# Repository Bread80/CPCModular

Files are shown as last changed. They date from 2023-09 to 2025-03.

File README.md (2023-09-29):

# The CPC Modular

### An Amstrad CPC compatible computer build from modules.

***This project is an unfinished work in progress. It currently has bugs and not all the features have been tested!

The current modules are designed to fit a slightly modified RC2014 Pro backplane. In the text below I shall explain the current status of the project, workarounds needed to get it running and basic build details. Due to the work in progress status of the project this document will be intentionaly terse.

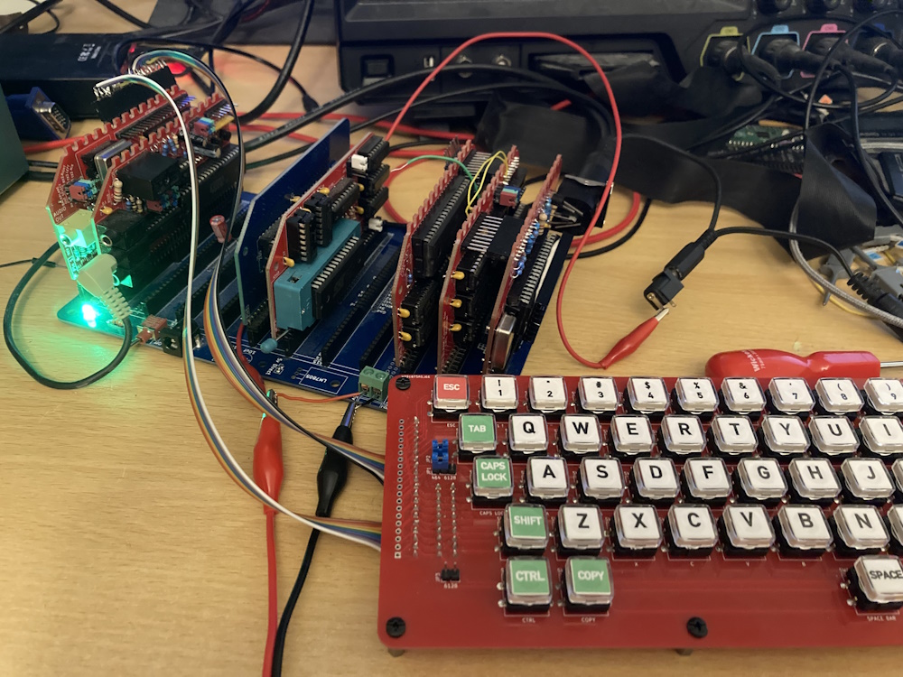
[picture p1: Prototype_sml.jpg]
Photo of the project. An RC2014 backplane in blue with modules in red.


## The modules

### General

The project uses pin header/socket to connect modules within subsystems (the video-RAM subsystem and the IO-sound sub-system). This requires longer pin header than usual.

### Backplane

This is a slightly modified RC2014 Pro backplane. The CPC Modular uses the D8 through D15 lines both within the video-RAM subsystem and the IO-Sound subsystem for local data busses. Therefore:
* You will need to sever the D8 through D15 lines between these sections. 

### CPU

This is a slightly modified RC2014 "Z80 CPU Module". Modification:
* The resistors on the board will need to be replaced with a different value. 2.2k ohm should work nicely.

### ROM

This board contains 512Kb NORFLASH. It includes circuitry to enable the flash to be burned in situ (untested). Config:
* A jumper needs to be installed bridging pin 2 of LK4 and pin 2 of LK5.
* To enable flash burning, install links LK1, LK2 and LK3. Otherwise leave open.
* My notes for writing to the Flash (taken from the schematic file) are:
> !!!
> There is no way to disable memory writes on the standard CPC system. Therefore ANY memory writes which we do to ROM while WRITE_EN is active will also write to RAM.
>
> However, since the ROM maps to any and all memory banks this adds a certain amount of flexibility. Also note that reading from ROM is disabled whilst writing is enabled. This means we can read from the RAM 'underneath' the ROM while the ROM is active.
>
> My recommended programming procedure is to write to the ROM using video RAM addresses, however the ROM could be writting using addresses in bank 1 (&4000-&7fff) if that memory range does not contain meaningful data. (If the data to be written is already in this address range then the programmer can simply read the data (RAM) and then write (ROM) at the same address. Care needs to be taking with commands sent to the ROM though, as these will still trash data underneath).
>
> 1) Read the RAM byte at the address to be programmed.
> 2) Turn on write enable for the ROM
> 3) Write the needed data to ROM.
> 4) Turn off write enable for the ROM
> 5) Write the original data back to ROM.

* The ROM (NORFLASH) can hold up to 31 ROMS plus the firmware ROM. When programming the chip, the Firmware needs to go into slot 31 (starting at address &7c000). BASIC (if installed) needs to go into slot 0 (address &00000). ROM slots are located every &4000 bytes, I.e &00000, &04000, &08000, &0C000, &10000 etc.
* If burning ROMs with the XGPro software:
  1) Use Select IC to select the IC being used (SST39FS040).
  2) Click LOAD toolbar button.
  3) Select the file to load.
  4) File Format: Binary (for .ROM files)
  5) To Region: Default
  6) Load mode: Normal
  7) From File Start Addr: 0000
  8) To Buffer Start Addr: The ROM slot start address (&7C000 for the firmware, &00000 for BASIC)
  9) Clear buffer when loading file: The option 'Clear buffer with default' will *overwrite* any previously loaded data! Use this for the first ROM loaded into XGPro (which will initialise the entire ROM). For all other ROMs select 'Disable' (which will load data only into the selected slot).
  10) Click Okay and verify you file(s) have loaded to the correct address(es) and not been overwritten.
  11) Click PROG (toolbar)
  12) Click Program.

### Video

This board houses the gate array and video output.
* On JP901 the DISPEN and HSYNC signals are swapped compared to those on the equivalent header on the RAM-Control board. This is best fixed on the RAM-Control board (see below).
* The video out circuit is that from the CPC464 but, somehow, I've used component values from the CPC6128 but minus the capacitors on the '6128. This probably doesn't make a significant difference.
* In my testing I'm using the same SCART to HDMI adapter I normally use for Amstrads but here it shows a black and white image, or no image at all. This appears to be an issue between the PSU used by the cable and the adapter. It can be fixed by feeding 5V power to the cable from the CPC Modular board.
* The board includes footprints for both 40007 and 40010 gate arrays (and a 40008 should also work). The footprints overlap to save space. You should be able to include sockets for both by separating the two rows of pins and removing the webbing between them, however, the footprints are a little too close together to do this easily.
* The holes in the footprint for the DIN socket are a little too small.

### RAM-Control

This board houses the link between the video data bus and the CPU data bus, massages the signals to make them suitable for the SRAM memory and houses the optional components required for memories greater than 64k (untested).
* The circuit driving /RAMOE is incorrect. To fix it:
  1) Cut the trace between U192 pins 1 and 13
  2) Cut the trace between U192 pin 11 and U193 pin 1
  3) Install a wire between U192 pin 1 and U195 pin 9
  4) Install a wire between U195 pin 8 and U193 pin 1
* As noted for the video board, the DISPEN and HSYNC pins are swapped on the connectors between the boards. To fix this:
  1) Cut the trace between J1 pin 2 and J2 pin 2
  2) Cut the trace between J1 pin 3 and J2 pin 3
  3) Install a wire between J1 pin 2 and J2 pin 3
  4) Install a wire between J1 pin 3 and J2 pin 2
* To use <= 64k RAM install links LK5, LK6 and LK7. If so DO NOT insert IC118 and U194
* To use > 64k RAM leave LK5, LK6, LK7 open and install IC118 and U194. IC118 is a standard Amstrad HAL/PAL.

The correct circuit to drive /RAMOE is:
```
XCPU_AD-----|
            |--
/XCPU_AD--     AND---/ROMOE
          OR---
/RAMRD----
```
In text form:
`/ROMOE := XCPU_AD AND (/XCPU_AD OR /RAMRD)`

XCPU_AD can be sourced from U195 pin 8.

### RAM

This board houses the 6845 CRTC, address multiplexers and 512Kb SRAM. There are no issues here, and no config is necessary.
* Headers can be installed for CURSOR and LPEN if required. They probably aren't.

### IO

This board houses the 8255 PIO and tape interface. Solder links and jumpers are installed to make the I/O address configurable:
* The board was designed such that the IO board could be mounted 'above/in front of' it but the relay is too tall to allow that. Thus: I'd recommend you mount J902 on the rear of the board (this is the connector to the Sound board).
* On the rear of the board find the solder links just above the address pins. On each link you need to solder the 'high' address pad (labelled A7(sic) to A15) to the central pad. The 'low' address pads (A0..A7) must NOT connected to the centre pads.
* On the front of the board find the links located between  U1 and D302. You need to jumper the 'low' link (to the centre pin) for the link labelled A3, and the high link (to the centre pin) for the others (A2, A4, A5, A6, A7).
* Find the links located between C315 and J901. The configure which signals are directed to the jack sockets and which are directed to the backplane. The recommended setup is:
  1) Install links between the INT(ernal) and middle pins for TO, TI and /MO (Tape Out, Tape In and Motor).
  2) Leave the /EXP link open.
* J901 allows access to various 8255 input signals. By default all these lines have pull-ups and can be ignored.
  1) RG0, RG1, RG2 are the region setting.
  2) VHz is the 50Hz/60Hz setting for video output.
  3) /EXP is the /EXP signal.
  4) PBSY is Printer Busy signal. The CPC Modular does not include a parallel port. This signal can be used for expansion if desired.
* J1, J2 and J3 are the tape I/O jacks. J3 (Motor) should be a 2.5mm jack socket but the footprint is for a 3.5mm socket.

### Sound

This board houses the AY-3-8910 sound generator and associated outputs, plus the keyboard and joystick connectors.
* As noted for the IO board: You should mount the inter-board connector (J902) on the top of this board, not the rear as shown in the silkscreen.
* The board has the ability to use an on-board oscillator for the AY's clock input. In the CPC Modular: Omit X1 and install a jumper at the CLK2 end of JP3 (which configures the board to use the clock signal from the gate array send through the backplane).
* The jumpers above J103 (audio out jack) allow various audio signals to be sent to a variety of backplane pins. In most cases these can be left open. Note that some of the settings may conflict with tape signals routed via the backplane on the IO board.
* If an audio jack is installed the LEFT and RIGHT signals will NOT be sent to the backplane (if configured to do so - see previous item). However the audio MIX will still be sent (if configured so).
* CP2 is the keyboard connector. This uses the same pinout as the original Amstrad CPC464 (PCB keyboard).
* J102 is the joystick connector. The connector here is mounted a little too 'inboard' and could short a PCB in the next socket.

## Links

HAL/PAL:
* Code for original: https://www.cpcwiki.eu/index.php/PAL16L8
* WiP replacement: https://github.com/Bread80/GreenHAL
* WiP replacement: https://www.cpcwiki.eu/forum/index.php?msg=231084

Gate Array:
* WiP FPGA based replacement: https://github.com/codedchip/AMSGateArray

ROM Images:
https://www.cpcwiki.eu/index.php/ROM_List

## Licence, Copyright and Contact Details

* Licence: CERN-OHL-P
* Copyright © Mike Sutton, 2023
* Website: https://bread80.com
* Social media (Mastodon): https://mstdn.social/@bread80

## Notes

There's nothing useful beyond here. But if you've made it this far you'll probably keep going anyway.

Signal lines
------------

Signals through RC2014 backplane
====

Common (whole board)
----
TX/RX=Sound (Left, right) **Jumpered (optional)
USR1=ROMDIS
USR2=/ROMEN
USR3=VSYNC (Video to IO)
USR4=<unusable>

/WAIT=READY (it already is!)
CLOCK2=/CPU_ADDR (RAM board; 1MHz clock for sound)
RX2=Tape in **Jumpered (optional)
TX2=Tape out **Jumpered (optional)
USR5=RAMDIS ***MOVED***
USR6=/RAMRD ***MOVED***
USR7=Motor **Jumpered (optional)

Video section
----
D8-D15=Video bus

IO Section
----
D8-D15=IO bus
???Control signals???

Signals through inter-board connectors
====

Video board to RAM Control board
----
Position=Top row of holes @ 45.72mm above centre of basic RC2014 header pins,
 Leftmost pins = mid-point between A9 and A8 
 Pin 1 to the right
1 GND
2 HSYNC (in)
3 DISPEN (in)
4 GND
5 /RAS (out)
6 /CAS (out)
7 /MWE (out)
8 /CCLK (out)
9 /244EN (out)
10 GND

RAM Control board to RAM board
----
Position=Top row of holes @ 43.18mm above centre of extended header pins, 
 Leftmost pins = mid-point between D2 and D3 pins
 Pin 1 to the left, all grounds on topmost row.
1=GND
2=HSYNC (in)
3=DISPEN (in)
4=/CCLK (out)
5=/XCPU_ADDR (out)
6=/RAMCS (out)
7=GND
8=/RAMOE (out)
9=GND
10=/RAMWE (out)
11=RAMA14 (out)
12=RAMA15 (out)
13=RAMA16 (out)
14=RAMA17 (out)
15=GND
16=RAMA18 (out)

IO board to Sound board
----
1=GND
2=BC1
3=BDIR
4=PC0
5=PC1
6=PC2
7=PC3
8=GND

Amstrad/MX4 pinout

Expansion  RAM Ctrl	RAM	Video	IO	AY	DDI
---
GND			
  SOUND							Y
A15			Y		Y	Y
  A14		Y		Y	Y
A13					Y
  A12				Y
A11					Y			Y
  A10				Y					Y
A9					Y			Y
  A8				Y			Y		Y
A7					Y					Y
  A6				Y
A5					Y
  A4				Y
A3					Y
  A2				Y
A1					Y			
  A0				Y					Y

D7			Y		Y			Y
  D6		Y		Y			Y
D5			Y		Y			Y
  D4		Y		Y			Y
D3			Y		Y			Y
  D2		Y		Y			Y
D1			Y		Y			Y
  D0		Y		Y			Y
					(CRTC)
VCC
  MREQ					Y
M1						Y		Y
  RFSH
IORQ				Y	Y		Y		Y
  RD				Y	Y		Y		Y
WR			Y		Y			Y		Y
  HALT
INT						Y
  NMI
BUSRQ
  BUSAK
READY		Y			Y
  BRST
RSET		Y?			Y?		Y?	Y?	Y?
  ROMEN					Y
ROMDIS		Y
  RAMRD		Y			Y
RAMDIS		
  CURSOR			Y
LPEN				Y
  EXP							Y		Y
GND
  CLK4					Y				Y

Extra (Video-RAM):
RD7..RD0	Y		Y	Y
RAS			Y			Y
CAS			Y			Y
MWE			Y			Y
244EN		Y			Y
XCPU_AD(?)	Y		Y
RAMCS		Y		Y
RAMOE		Y		Y
RAMWE		Y		Y	
RAMA18..RAMA14  Y	Y
HSYNC				Y	Y
DISPEN				Y	Y
CCLK				Y	Y
(24 lines)

Extra (Video-RAM and IO-Sound):
CPU_ADDR(1MHz) Y		Y		Y
VSYNC				Y	Y		Y
(2 lines)

Extra (IO-Sound):
PA7..PA0						Y	Y
MOTOR							Y
CASRD							Y
CASWR							Y
PRINTBUSY						(Y)
BC1								Y	Y
BDIR							Y	Y
PC3..PC0						Y	Y
LEFT								Y
RIGHT								Y
(20 lines)

Disc:
Approx 14 lines required internally

Video/RAM: 50 + 24 + 2 = 76 lines! total. Less un-needed: 69 total (70 plus one spare!)
IO/Sound: 50 + 20 + 2 = 72 lines total. Less un-needed: 50 total (inc a couple of spares)
Disc: 50 + 14 = 64 lines total

Notes:
76 pin edge connector: board width = 99.06mm

Boards:
MX4 section:
CPU
ROM
Spare(s)
RC2014
Edge connector

Video section (gate array):
Video
RAM
RAM Control

Video section (RP2040):
Video
Signals
RAM
Transceiver

Disc Section:
Controller
Connectors/Buffers

IO Sound section:
PPI
AY
Tape
Audio amp/mixer

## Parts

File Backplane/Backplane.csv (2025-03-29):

Source: | C:\Dropbox\InfoLaptop\Bread80\CPC\CPCModular\Backplane\Backplane.sch
Date: | 06/03/2024 22:52
Tool: | Eeschema (5.1.12)-1
Generator: | C:\Program Files\KiCad\bin\scripting\plugins/bom_csv_grouped_by_value_with_fp.py
Component Count: | 90
Ref | Qnty | Value | Cmp name | Footprint | Description | Vendor
C1, C3, | 2 | 220uF 100V | CP | Capacitor_THT:CP_Radial_D7.5mm_P2.50mm | Polarized capacitor
C2, | 1 | 470uF 6.3V | CP | Capacitor_THT:CP_Radial_D7.5mm_P2.50mm | Polarized capacitor
C4, | 1 | 10V 47uF | CP | Capacitor_THT:CP_Radial_D7.5mm_P2.50mm | Polarized capacitor
D1, D2, | 2 | SA5.0CA-E3/54 | D_TVS_ALT | Diode_THT:D_DO-15_P12.70mm_Horizontal | Bidirectional transient-voltage-suppression diode, filled shape
D3, | 1 | POWER | LED | LED_THT:LED_D3.0mm | Light emitting diode
D4, D5, D6, D7, D8, D9, D10, D11, D12, D13, D14, D15, D16, D17, D18, D19, D20, D21, D22, D23, D24, D25, D26, D27, D28, D29, D30, D31, D32, D33, D34, D35, D36, D37, D38, D39, D40, D41, D42, D43, D44, D45, D46, D47, D48, D49, D50, D51, | 48 | PESD5V0V1BA | D_TVS_ALT | Diode_SMD:D_SOD-323_HandSoldering | Bidirectional transient-voltage-suppression diode, filled shape
D52, | 1 | 1N4148 | 1N4148 | Diode_THT:D_DO-35_SOD27_P7.62mm_Horizontal | 100V 0.15A standard switching diode, DO-35
D53, | 1 | SA12CA | D_TVS_ALT | Diode_THT:D_DO-15_P12.70mm_Horizontal | Bidirectional transient-voltage-suppression diode, filled shape
F1, | 1 | MF-R600-2 | Fuse | Fuse:Fuse_Bourns_MF-RG600 | Fuse
H1, H2, H3, H4, H5, H6, | 6 | MountingHole_Pad | MountingHole_Pad | MountingHole:MountingHole_3.2mm_M3 | Mounting Hole with connection
J1, J2, J3, J4, | 4 | Conn_02x25_Odd_Even | Conn_02x25_Odd_Even | Connector_PinSocket_2.54mm:PinSocket_2x25_P2.54mm_Vertical | Generic connector, double row, 02x25, odd/even pin numbering scheme (row 1 odd numbers, row 2 even numbers), script generated (kicad-library-utils/schlib/autogen/connector/)
J5, J6, J7, J8, | 4 | Conn_02x36_Top_Bottom | Conn_02x36_Top_Bottom | CPCModular:Edge_Socket_2x36_2.54PS | Generic connector, double row, 02x36, top/bottom pin numbering scheme (row 1: 1...pins_per_row, row2: pins_per_row+1 ... num_pins), script generated (kicad-library-utils/schlib/autogen/connector/)
J9, J10, J11, | 3 | Conn_02x25_Top_Bottom | Conn_02x25_Top_Bottom | CPCModular:Edge_Socket_2x25_2.54PS | Generic connector, double row, 02x25, top/bottom pin numbering scheme (row 1: 1...pins_per_row, row2: pins_per_row+1 ... num_pins), script generated (kicad-library-utils/schlib/autogen/connector/)
J12, | 1 | Expansion Top (Edge connector) | Conn_01x25_Male | CPCModular:Edge25_2.54PS | Generic connector, single row, 01x25, script generated (kicad-library-utils/schlib/autogen/connector/)
J13, | 1 | Expansion Bottom (Edge connector) | Conn_01x25_Male | CPCModular:Edge25_2.54PS | Generic connector, single row, 01x25, script generated (kicad-library-utils/schlib/autogen/connector/)
J14, | 1 | USB_B | USB_B | Connector_USB:USB_B_OST_USB-B1HSxx_Horizontal | USB Type B connector
J15, | 1 | TE 171826-4 | Conn_01x04_Female | Connector_JST:JST_EH_S4B-EH_1x04_P2.50mm_Horizontal | Generic connector, single row, 01x04, script generated (kicad-library-utils/schlib/autogen/connector/)
J16, | 1 | Barrel_Jack_MountingPin | Barrel_Jack_MountingPin | Connector_BarrelJack:BarrelJack_Horizontal | DC Barrel Jack with a mounting pin
J17, | 1 | SCART POWER | Conn_01x02_Male | Connector_PinHeader_2.54mm:PinHeader_1x02_P2.54mm_Horizontal | Generic connector, single row, 01x02, script generated (kicad-library-utils/schlib/autogen/connector/)
R1, | 1 | 470 | R | Resistor_THT:R_Axial_DIN0207_L6.3mm_D2.5mm_P7.62mm_Horizontal | Resistor
R2, | 1 | 22k | R | Resistor_THT:R_Axial_DIN0207_L6.3mm_D2.5mm_P7.62mm_Horizontal | Resistor
R3, | 1 | 2k2 | R | Resistor_THT:R_Axial_DIN0207_L6.3mm_D2.5mm_P7.62mm_Horizontal | Resistor
SW1, | 1 | SSP1S1M6xEA | SW_SPDT | CPCModular:E-Switch_SSP1_M6_A | Switch, single pole double throw
SW2, | 1 | PTS645VH58-2 LFS | SW_Push | Button_Switch_THT:SW_Tactile_SPST_Angled_PTS645Vx58-2LFS | Push button switch, generic, two pins
TH1, | 1 | B57238S0709M000 | Thermistor_NTC | Varistor:RV_Disc_D15.5mm_W5.9mm_P7.5mm | Temperature dependent resistor, negative temperature coefficient
U1, | 1 | RS6-0505S | RS6-0505S | CPCModular:Recom_RS6_Series_SIP8 | Recom RS6-0505S DC/DC converter. 4.5-9Vin, 5Vout, 6W, SIP8
U2, | 1 | 74LS132 | 74LS132 | Package_DIP:DIP-14_W7.62mm_Socket | Quad 2-input NAND Schmitt trigger
U3, | 1 | TMU 3-0512 | CRE1S2412SC | Converter_DCDC:Converter_DCDC_muRata_CRE1xxxxxxSC_THT | 24V to 12V 83mA DC-DC Converter with 1kV isolation, SIP-4

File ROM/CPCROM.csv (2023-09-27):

Source: | C:\Dropbox\InfoLaptop\Bread80\CPC\CPCModular\ROM\CPCROM.sch
Date: | 01/02/2022 15:57
Tool: | Eeschema (5.1.7)-1
Generator: | C:\Program Files\KiCad\bin\scripting\plugins/bom_csv_grouped_by_value_with_fp.py
Component Count: | 26
Ref | Qnty | Value | Cmp name | Footprint | Description | Vendor
IC103, | 1 | SST39SF040 | SST39SF040 | Package_DIP:DIP-32_W15.24mm_Socket | Silicon Storage Technology (SSF) 512k x 8 Flash ROM
 |  | ZIF Socket

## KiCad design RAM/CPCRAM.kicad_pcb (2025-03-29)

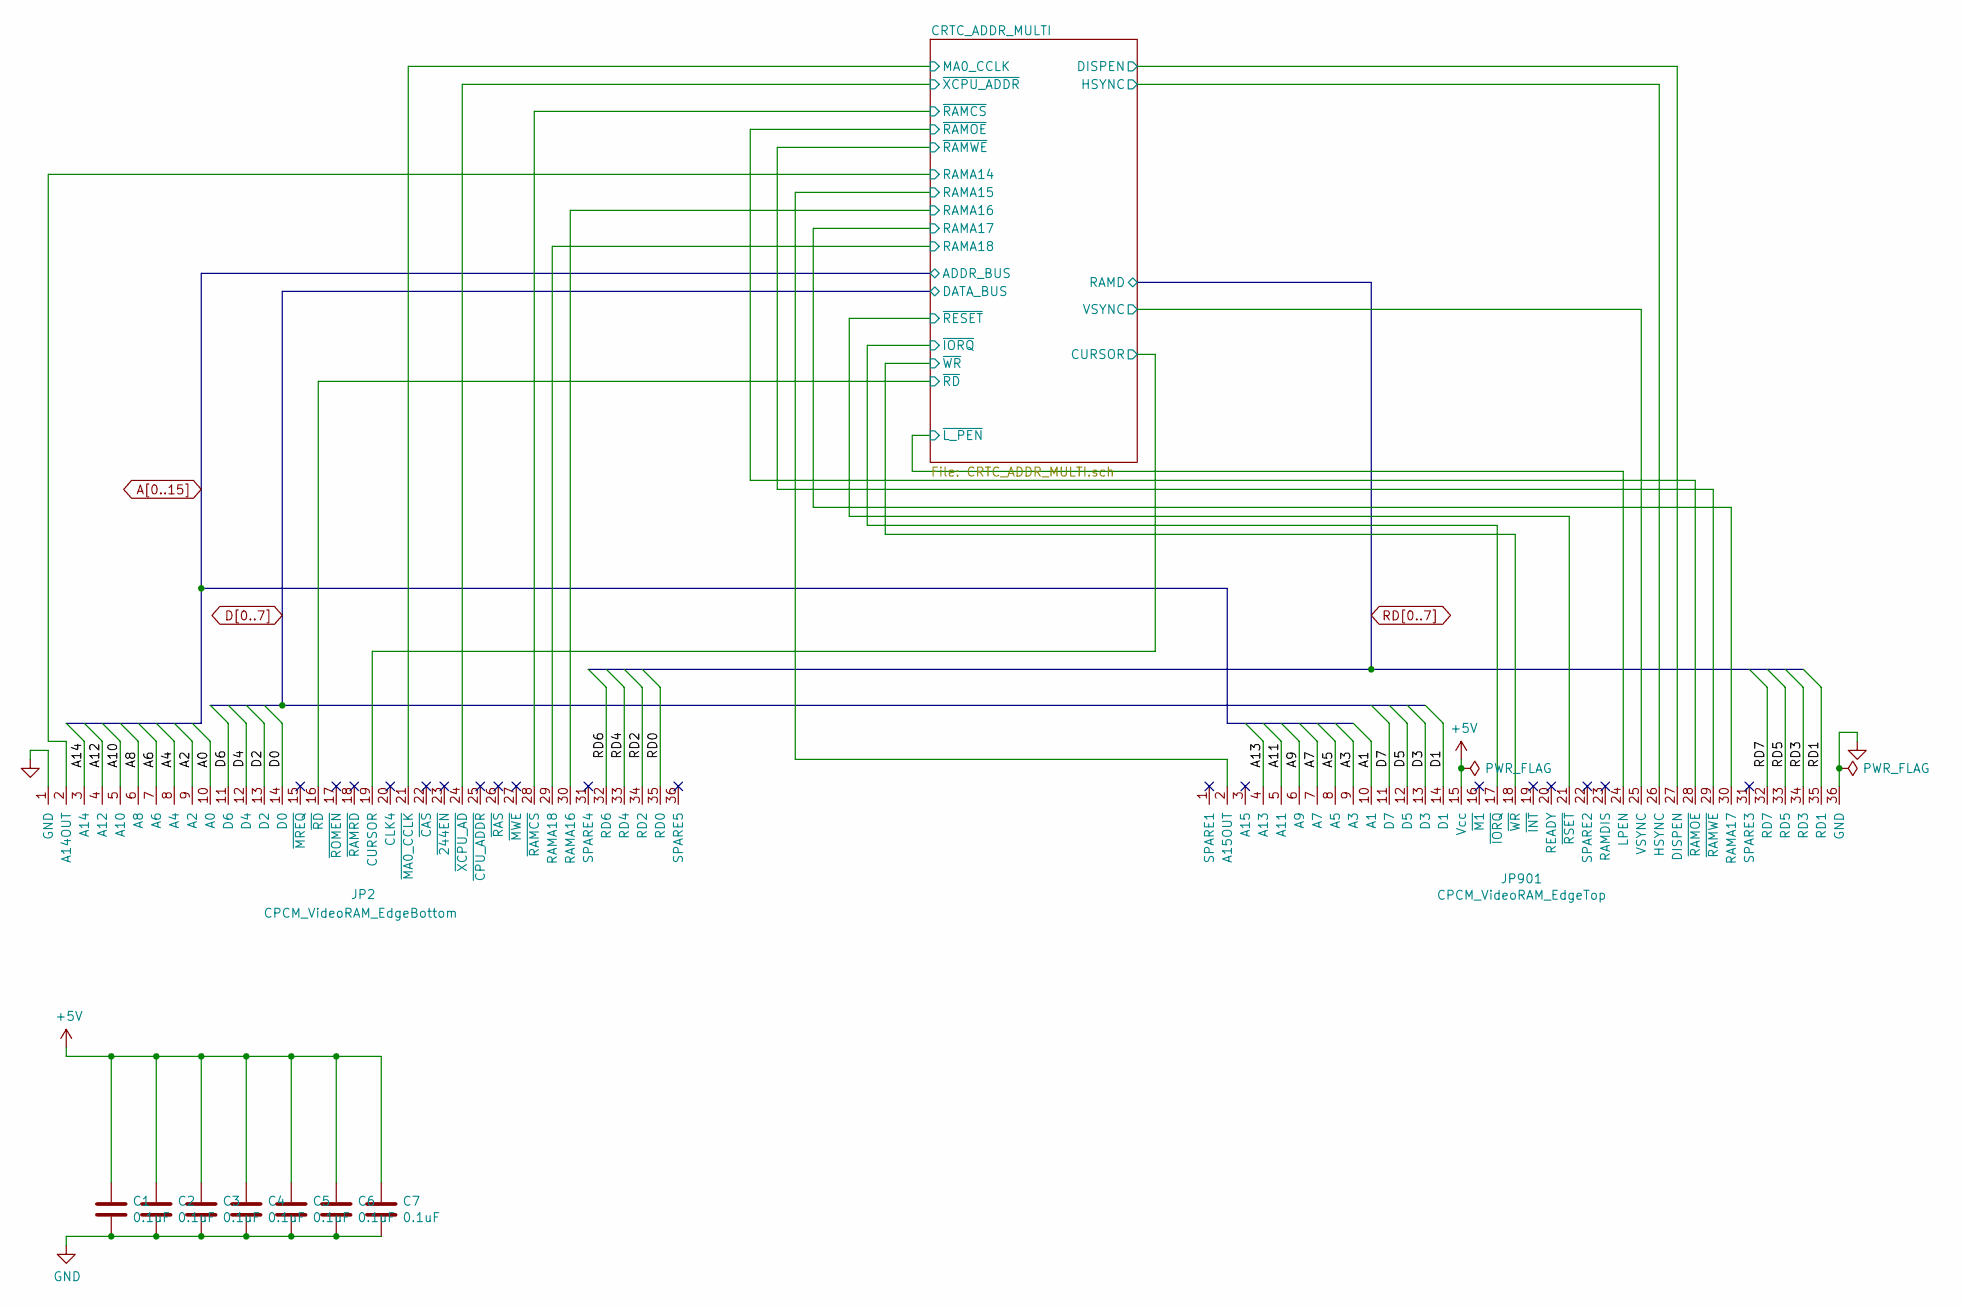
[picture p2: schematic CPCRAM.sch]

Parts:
C1, C2, C3, C4, C5, C6, C7: 0.1uF; C_Disc_D3.0mm_W2.0mm_P2.50mm
JP2: CPCM_VideoRAM_EdgeBottom; Edge36_2.54PS
JP901: CPCM_VideoRAM_EdgeTop; Edge36_2.54PS

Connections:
+5V: C1.1, C2.1, C3.1, C4.1, C5.1, C6.1, C7.1, JP901.15 (Vcc); also elsewhere on the board
/CRTC_ADDR_MULTI/A14OUT: JP2.2 (A14OUT); also elsewhere on the board
/CRTC_ADDR_MULTI/A15OUT: JP901.2 (A15OUT); also elsewhere on the board
/CRTC_ADDR_MULTI/CURSOR: JP2.19 (CURSOR); also elsewhere on the board
/CRTC_ADDR_MULTI/DISPEN: JP901.27 (DISPEN); also elsewhere on the board
/CRTC_ADDR_MULTI/HSYNC: JP901.26 (HSYNC); also elsewhere on the board
/CRTC_ADDR_MULTI/MA0_CCLK: JP2.21 (~MA0_CCLK); also elsewhere on the board
/CRTC_ADDR_MULTI/VSYNC: JP901.25 (VSYNC); also elsewhere on the board
/CRTC_ADDR_MULTI/~IORQ: JP901.17 (~IORQ); also elsewhere on the board
/CRTC_ADDR_MULTI/~L_PEN: JP901.24 (LPEN); also elsewhere on the board
/CRTC_ADDR_MULTI/~RAMCS: JP2.28 (~RAMCS); also elsewhere on the board
/CRTC_ADDR_MULTI/~RAMOE: JP901.28 (~RAMOE); also elsewhere on the board
/CRTC_ADDR_MULTI/~RAMWE: JP901.29 (~RAMWE); also elsewhere on the board
/CRTC_ADDR_MULTI/~RD: JP2.16 (~RD); also elsewhere on the board
/CRTC_ADDR_MULTI/~RESET: JP901.21 (~RSET); also elsewhere on the board
/CRTC_ADDR_MULTI/~WR: JP901.18 (~WR); also elsewhere on the board
/CRTC_ADDR_MULTI/~XCPU_ADDR: JP2.24 (~XCPU_AD); also elsewhere on the board
A0: JP2.10 (A0); also elsewhere on the board
A1: JP901.10 (A1); also elsewhere on the board
A2: JP2.9 (A2); also elsewhere on the board
A3: JP901.9 (A3); also elsewhere on the board
A4: JP2.8 (A4); also elsewhere on the board
A5: JP901.8 (A5); also elsewhere on the board
A6: JP2.7 (A6); also elsewhere on the board
A7: JP901.7 (A7); also elsewhere on the board
A8: JP2.6 (A8); also elsewhere on the board
A9: JP901.6 (A9); also elsewhere on the board
A10: JP2.5 (A10); also elsewhere on the board
A11: JP901.5 (A11); also elsewhere on the board
A12: JP2.4 (A12); also elsewhere on the board
A13: JP901.4 (A13); also elsewhere on the board
A14: JP2.3 (A14); also elsewhere on the board
D0: JP2.14 (D0); also elsewhere on the board
D1: JP901.14 (D1); also elsewhere on the board
D2: JP2.13 (D2); also elsewhere on the board
D3: JP901.13 (D3); also elsewhere on the board
D4: JP2.12 (D4); also elsewhere on the board
D5: JP901.12 (D5); also elsewhere on the board
D6: JP2.11 (D6); also elsewhere on the board
D7: JP901.11 (D7); also elsewhere on the board
GND: C1.2, C2.2, C3.2, C4.2, C5.2, C6.2, C7.2, JP2.1 (GND), JP901.36 (GND); also elsewhere on the board
RAMA16: JP2.30 (RAMA16); also elsewhere on the board
RAMA17: JP901.30 (RAMA17); also elsewhere on the board
RAMA18: JP2.29 (RAMA18); also elsewhere on the board
RD0: JP2.35 (RD0); also elsewhere on the board
RD1: JP901.35 (RD1); also elsewhere on the board
RD2: JP2.34 (RD2); also elsewhere on the board
RD3: JP901.34 (RD3); also elsewhere on the board
RD4: JP2.33 (RD4); also elsewhere on the board
RD5: JP901.33 (RD5); also elsewhere on the board
RD6: JP2.32 (RD6); also elsewhere on the board
RD7: JP901.32 (RD7); also elsewhere on the board

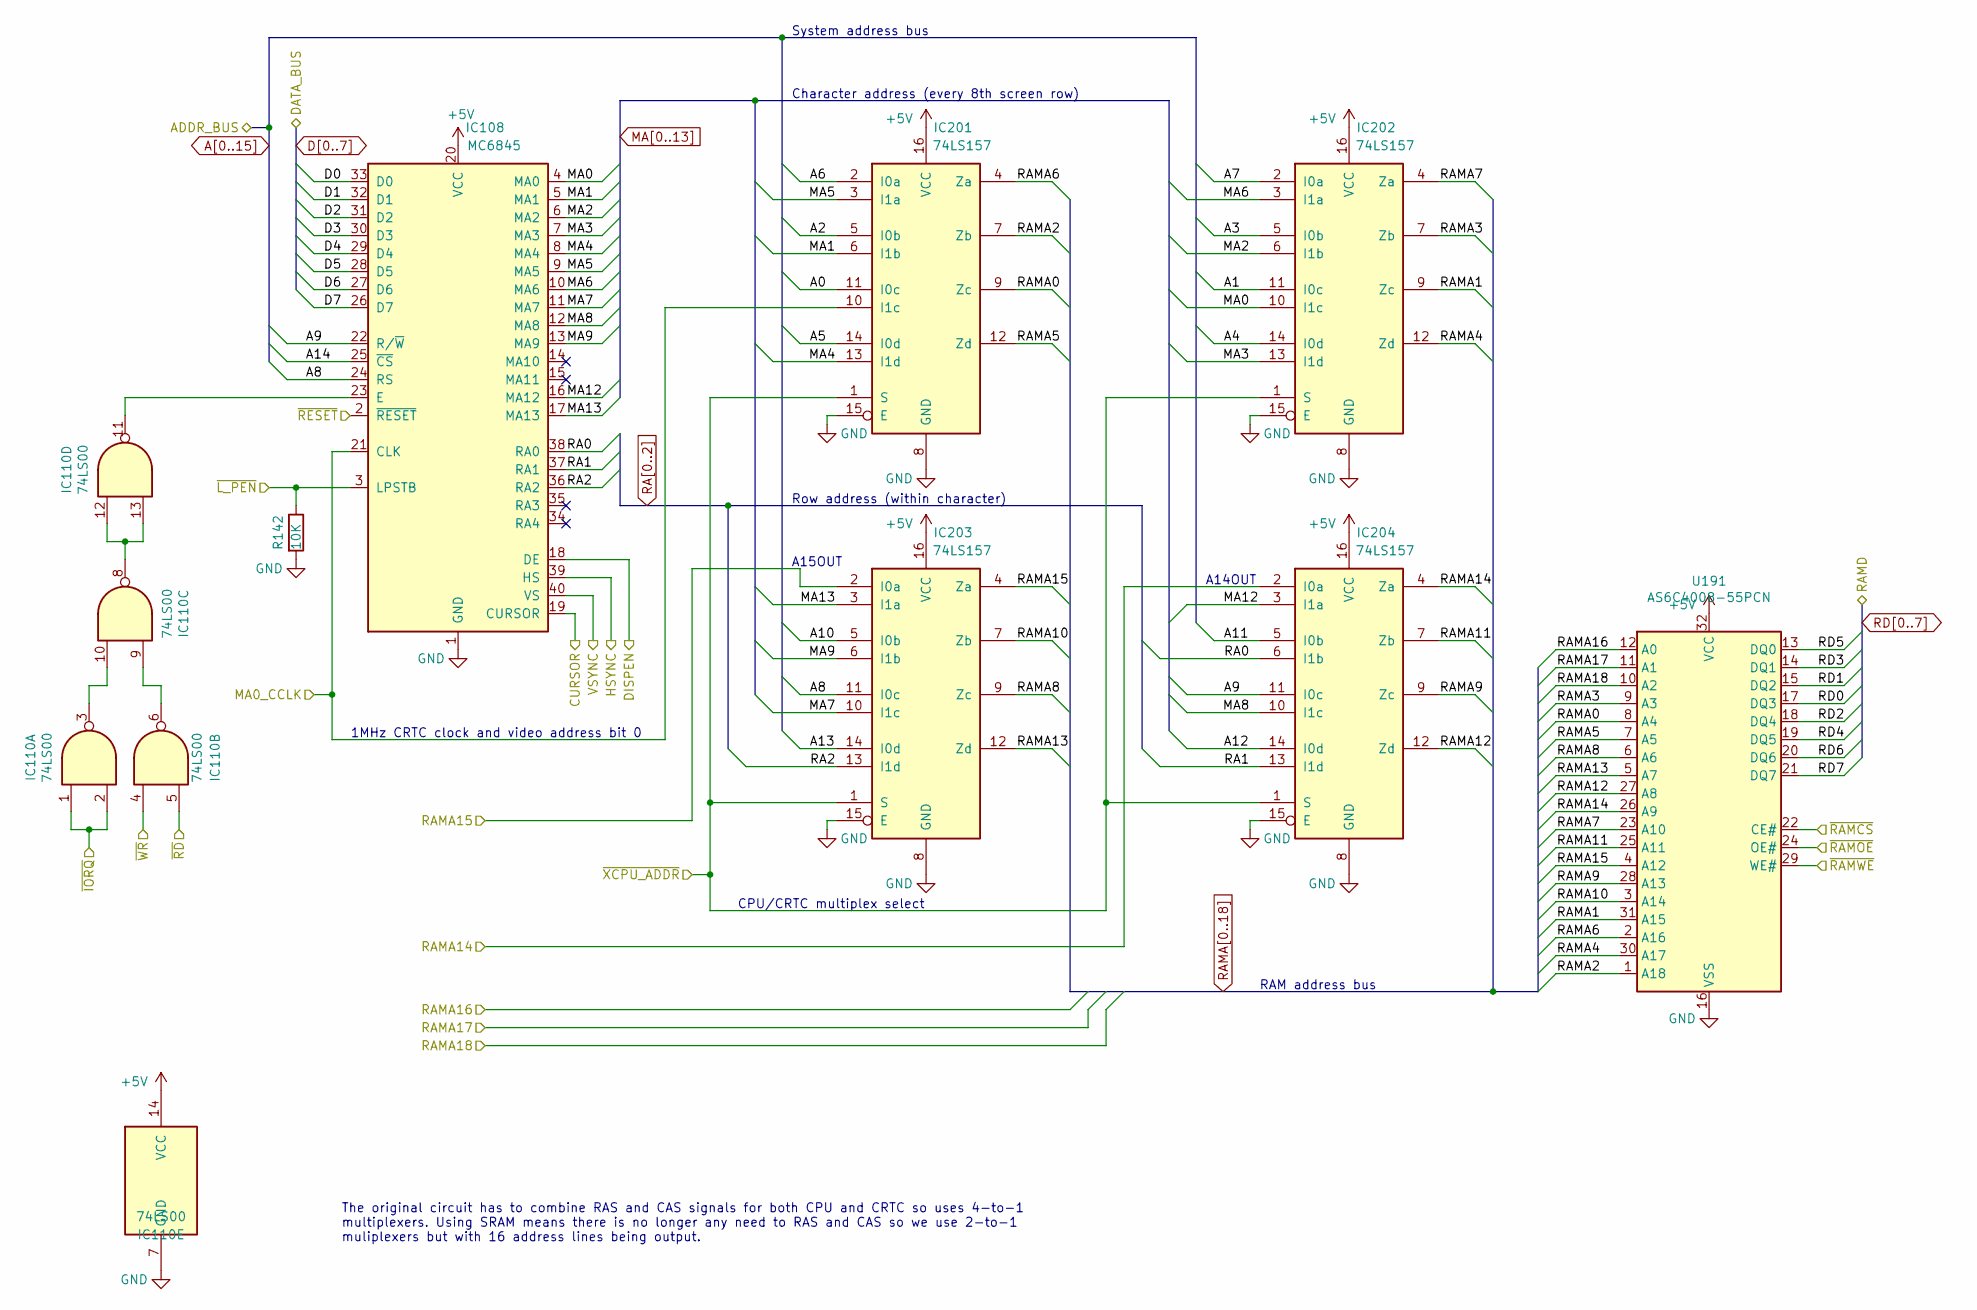
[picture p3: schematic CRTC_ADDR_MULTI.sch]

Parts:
IC108: MC6845; DIP-40_W15.24mm_Socket
IC110: 74LS00; DIP-14_W7.62mm_Socket
IC201, IC202, IC203, IC204: 74LS157; DIP-16_W7.62mm_Socket
R142: 10K; R_Axial_DIN0207_L6.3mm_D2.5mm_P7.62mm_Horizontal
U191: AS6C4008-55PCN; DIP-32_W15.24mm

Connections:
+5V: IC108.20 (VCC), IC110.14 (VCC), IC201.16 (VCC), IC202.16 (VCC), IC203.16 (VCC), IC204.16 (VCC), U191.32 (VCC); also elsewhere on the board
/CRTC_ADDR_MULTI/A14OUT: IC204.2 (I0a); also elsewhere on the board
/CRTC_ADDR_MULTI/A15OUT: IC203.2 (I0a); also elsewhere on the board
/CRTC_ADDR_MULTI/CURSOR: IC108.19 (CURSOR); also elsewhere on the board
/CRTC_ADDR_MULTI/DISPEN: IC108.18 (DE); also elsewhere on the board
/CRTC_ADDR_MULTI/HSYNC: IC108.39 (HS); also elsewhere on the board
/CRTC_ADDR_MULTI/MA0_CCLK: IC108.21 (CLK), IC201.10 (I1c); also elsewhere on the board
/CRTC_ADDR_MULTI/VSYNC: IC108.40 (VS); also elsewhere on the board
/CRTC_ADDR_MULTI/~IORQ: IC110.1, IC110.2; also elsewhere on the board
/CRTC_ADDR_MULTI/~L_PEN: IC108.3 (LPSTB), R142.1; also elsewhere on the board
/CRTC_ADDR_MULTI/~RAMCS: U191.22 (CE#); also elsewhere on the board
/CRTC_ADDR_MULTI/~RAMOE: U191.24 (OE#); also elsewhere on the board
/CRTC_ADDR_MULTI/~RAMWE: U191.29 (WE#); also elsewhere on the board
/CRTC_ADDR_MULTI/~RD: IC110.5; also elsewhere on the board
/CRTC_ADDR_MULTI/~RESET: IC108.2 (~RESET); also elsewhere on the board
/CRTC_ADDR_MULTI/~WR: IC110.4; also elsewhere on the board
/CRTC_ADDR_MULTI/~XCPU_ADDR: IC201.1 (S), IC202.1 (S), IC203.1 (S), IC204.1 (S); also elsewhere on the board
A0: IC201.11 (I0c); also elsewhere on the board
A1: IC202.11 (I0c); also elsewhere on the board
A2: IC201.5 (I0b); also elsewhere on the board
A3: IC202.5 (I0b); also elsewhere on the board
A4: IC202.14 (I0d); also elsewhere on the board
A5: IC201.14 (I0d); also elsewhere on the board
A6: IC201.2 (I0a); also elsewhere on the board
A7: IC202.2 (I0a); also elsewhere on the board
A8: IC108.24 (RS), IC203.11 (I0c); also elsewhere on the board
A9: IC108.22 (R/~W), IC204.11 (I0c); also elsewhere on the board
A10: IC203.5 (I0b); also elsewhere on the board
A11: IC204.5 (I0b); also elsewhere on the board
A12: IC204.14 (I0d); also elsewhere on the board
A13: IC203.14 (I0d); also elsewhere on the board
A14: IC108.25 (~CS); also elsewhere on the board
D0: IC108.33 (D0); also elsewhere on the board
D1: IC108.32 (D1); also elsewhere on the board
D2: IC108.31 (D2); also elsewhere on the board
D3: IC108.30 (D3); also elsewhere on the board
D4: IC108.29 (D4); also elsewhere on the board
D5: IC108.28 (D5); also elsewhere on the board
D6: IC108.27 (D6); also elsewhere on the board
D7: IC108.26 (D7); also elsewhere on the board
GND: IC108.1 (GND), IC110.7 (GND), IC201.8 (GND), IC201.15 (E), IC202.8 (GND), IC202.15 (E), IC203.8 (GND), IC203.15 (E), IC204.8 (GND), IC204.15 (E), R142.2, U191.16 (VSS); also elsewhere on the board
MA0: IC108.4 (MA0), IC202.10 (I1c)
MA1: IC108.5 (MA1), IC201.6 (I1b)
MA2: IC108.6 (MA2), IC202.6 (I1b)
MA3: IC108.7 (MA3), IC202.13 (I1d)
MA4: IC108.8 (MA4), IC201.13 (I1d)
MA5: IC108.9 (MA5), IC201.3 (I1a)
MA6: IC108.10 (MA6), IC202.3 (I1a)
MA7: IC108.11 (MA7), IC203.10 (I1c)
MA8: IC108.12 (MA8), IC204.10 (I1c)
MA9: IC108.13 (MA9), IC203.6 (I1b)
MA12: IC108.16 (MA12), IC204.3 (I1a)
MA13: IC108.17 (MA13), IC203.3 (I1a)
unnamed: IC108.23 (E), IC110.11
unnamed: IC110.6, IC110.9
unnamed: IC110.3, IC110.10
unnamed: IC110.8, IC110.12, IC110.13
RA0: IC108.38 (RA0), IC204.6 (I1b)
RA1: IC108.37 (RA1), IC204.13 (I1d)
RA2: IC108.36 (RA2), IC203.13 (I1d)
RAMA0: IC201.9 (Zc), U191.8 (A4)
RAMA1: IC202.9 (Zc), U191.31 (A15)
RAMA2: IC201.7 (Zb), U191.1 (A18)
RAMA3: IC202.7 (Zb), U191.9 (A3)
RAMA4: IC202.12 (Zd), U191.30 (A17)
RAMA5: IC201.12 (Zd), U191.7 (A5)
RAMA6: IC201.4 (Za), U191.2 (A16)
RAMA7: IC202.4 (Za), U191.23 (A10)
RAMA8: IC203.9 (Zc), U191.6 (A6)
RAMA9: IC204.9 (Zc), U191.28 (A13)
RAMA10: IC203.7 (Zb), U191.3 (A14)
RAMA11: IC204.7 (Zb), U191.25 (A11)
RAMA12: IC204.12 (Zd), U191.27 (A8)
RAMA13: IC203.12 (Zd), U191.5 (A7)
RAMA14: IC204.4 (Za), U191.26 (A9)
RAMA15: IC203.4 (Za), U191.4 (A12)
RAMA16: U191.12 (A0); also elsewhere on the board
RAMA17: U191.11 (A1); also elsewhere on the board
RAMA18: U191.10 (A2); also elsewhere on the board
RD0: U191.17 (DQ3); also elsewhere on the board
RD1: U191.15 (DQ2); also elsewhere on the board
RD2: U191.18 (DQ4); also elsewhere on the board
RD3: U191.14 (DQ1); also elsewhere on the board
RD4: U191.19 (DQ5); also elsewhere on the board
RD5: U191.13 (DQ0); also elsewhere on the board
RD6: U191.20 (DQ6); also elsewhere on the board
RD7: U191.21 (DQ7); also elsewhere on the board

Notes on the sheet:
The original circuit has to combine RAS and CAS signals for both CPU and CRTC so uses 4-to-1 multiplexers. Using SRAM means there is no longer any need to RAS and CAS so we use 2-to-1 muliplexers but with 16 address lines being output.
Row address (within character)
Character address (every 8th screen row)
CPU/CRTC multiplex select
1MHz CRTC clock and video address bit 0
System address bus
A14OUT
A15OUT
RAM address bus

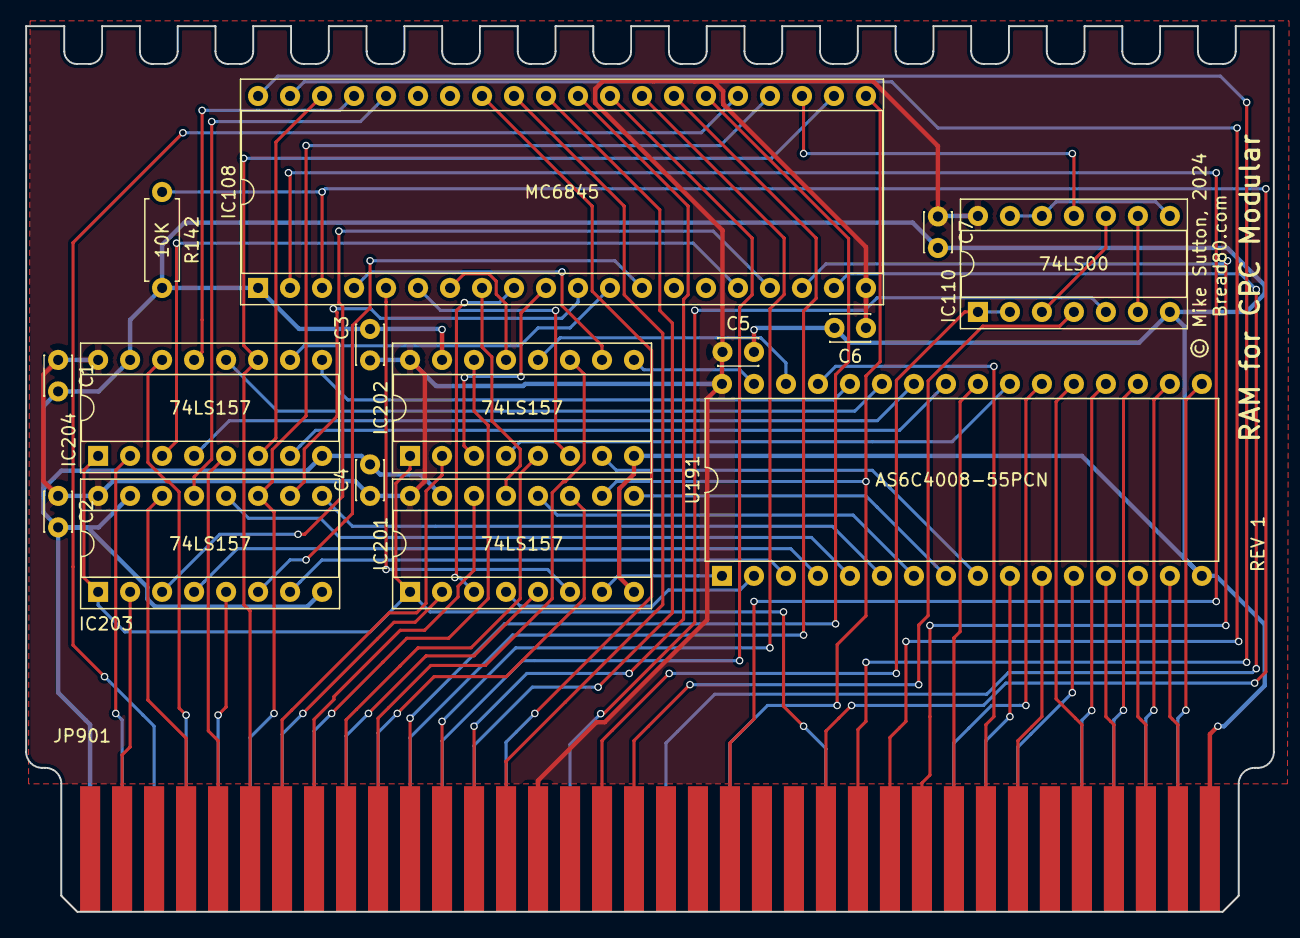
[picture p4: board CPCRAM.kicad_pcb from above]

Board: 2 copper layers, 99.1 x 70.3 mm, 17 parts (1 on the bottom side), 87 nets.

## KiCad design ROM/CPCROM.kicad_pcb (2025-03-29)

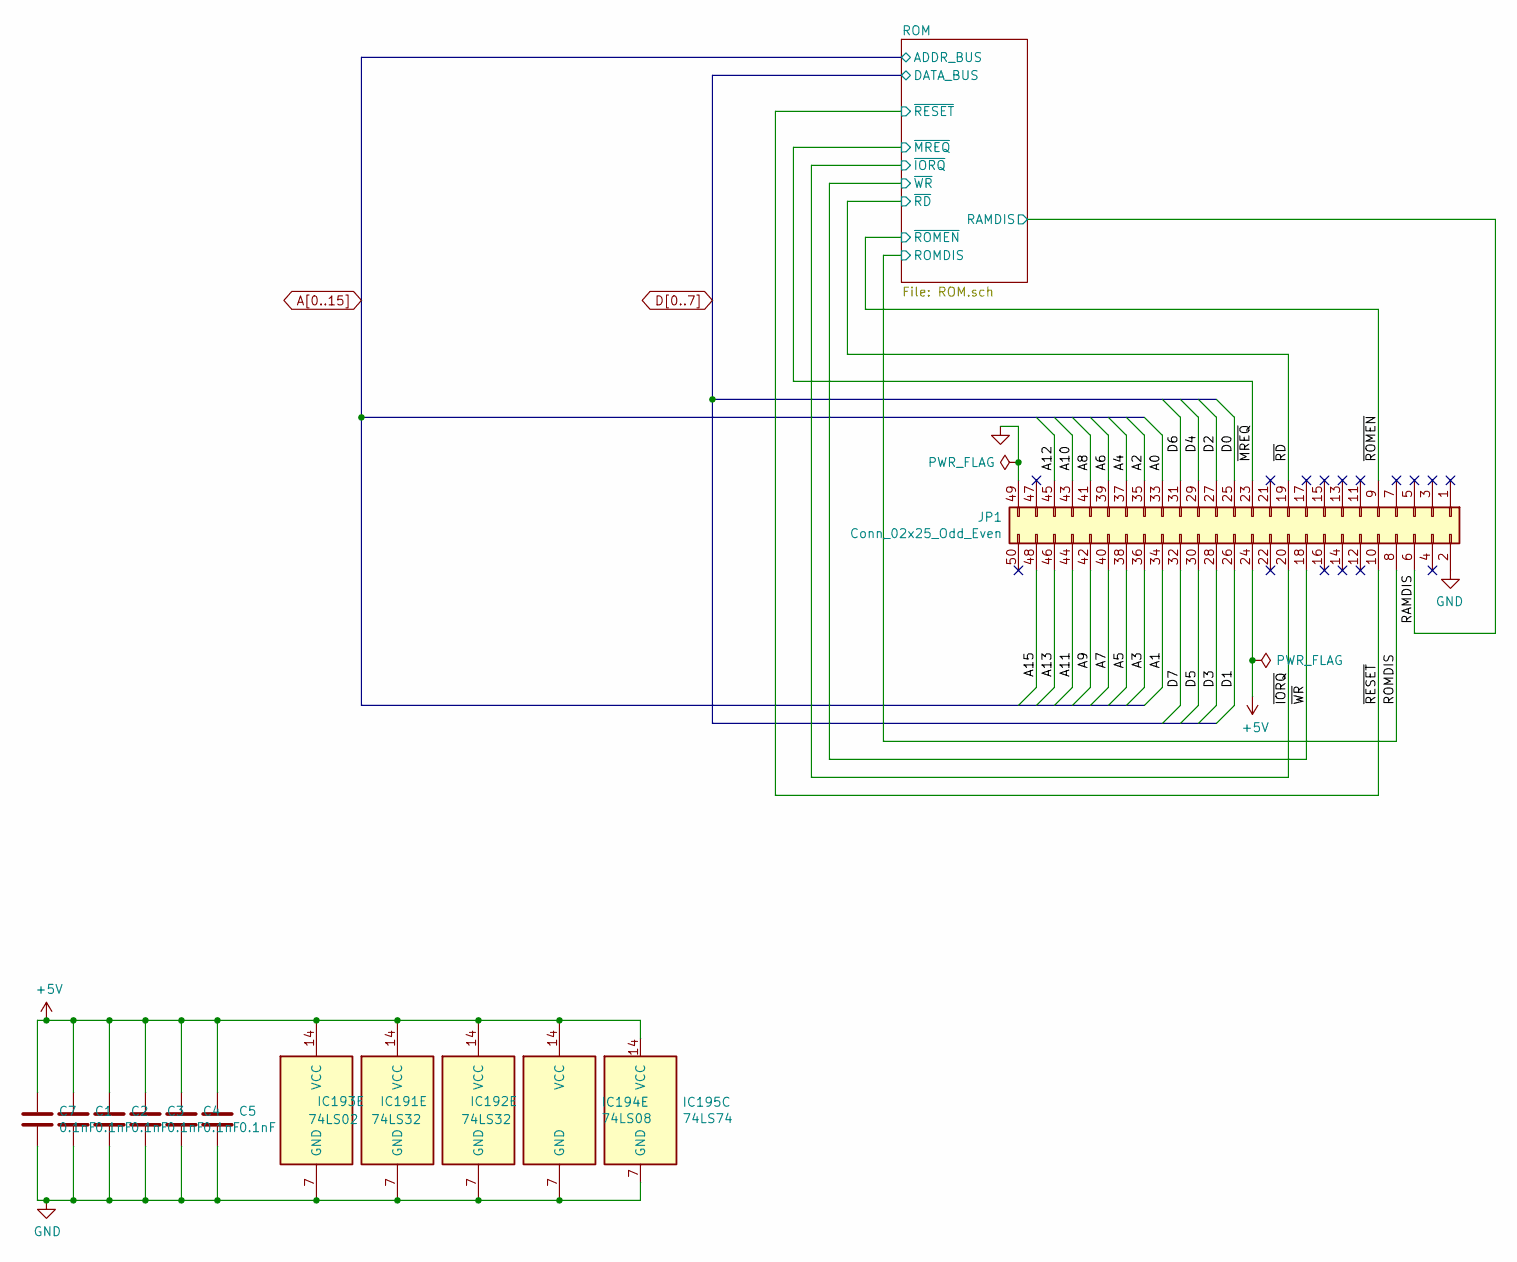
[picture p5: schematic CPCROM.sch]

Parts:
C1, C2, C3, C4, C5, C7: 0.1nF; C_Disc_D3.0mm_W2.0mm_P2.50mm
IC191, IC192: 74LS32
IC193: 74LS02
IC194: 74LS08
IC195: 74LS74
JP1: Conn_02x25_Odd_Even; IDC-Header_2x25_P2.54mm_Horizontal

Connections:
+5V: C1.1, C2.1, C3.1, C4.1, C5.1, C7.1, IC191.14 (VCC), IC192.14 (VCC), IC193.14 (VCC), IC194.14 (VCC), IC195.14 (VCC), JP1.24; also elsewhere on the board
/RAMDIS: JP1.6; also elsewhere on the board
/ROMDIS: JP1.8; also elsewhere on the board
/~IORQ: JP1.20; also elsewhere on the board
/~MREQ: JP1.23; also elsewhere on the board
/~RD: JP1.19; also elsewhere on the board
/~RESET: JP1.10; also elsewhere on the board
/~ROMEN: JP1.9; also elsewhere on the board
/~WR: JP1.18; also elsewhere on the board
A0: JP1.33; also elsewhere on the board
A1: JP1.34; also elsewhere on the board
A2: JP1.35; also elsewhere on the board
A3: JP1.36; also elsewhere on the board
A4: JP1.37; also elsewhere on the board
A5: JP1.38; also elsewhere on the board
A6: JP1.39; also elsewhere on the board
A7: JP1.40; also elsewhere on the board
A8: JP1.41; also elsewhere on the board
A9: JP1.42; also elsewhere on the board
A10: JP1.43; also elsewhere on the board
A11: JP1.44; also elsewhere on the board
A12: JP1.45; also elsewhere on the board
A13: JP1.46; also elsewhere on the board
A15: JP1.48; also elsewhere on the board
D0: JP1.25; also elsewhere on the board
D1: JP1.26; also elsewhere on the board
D2: JP1.27; also elsewhere on the board
D3: JP1.28; also elsewhere on the board
D4: JP1.29; also elsewhere on the board
D5: JP1.30; also elsewhere on the board
D6: JP1.31; also elsewhere on the board
D7: JP1.32; also elsewhere on the board
GND: C1.2, C2.2, C3.2, C4.2, C5.2, C7.2, IC191.7 (GND), IC192.7 (GND), IC193.7 (GND), IC194.7 (GND), IC195.7 (GND), JP1.2, JP1.49; also elsewhere on the board

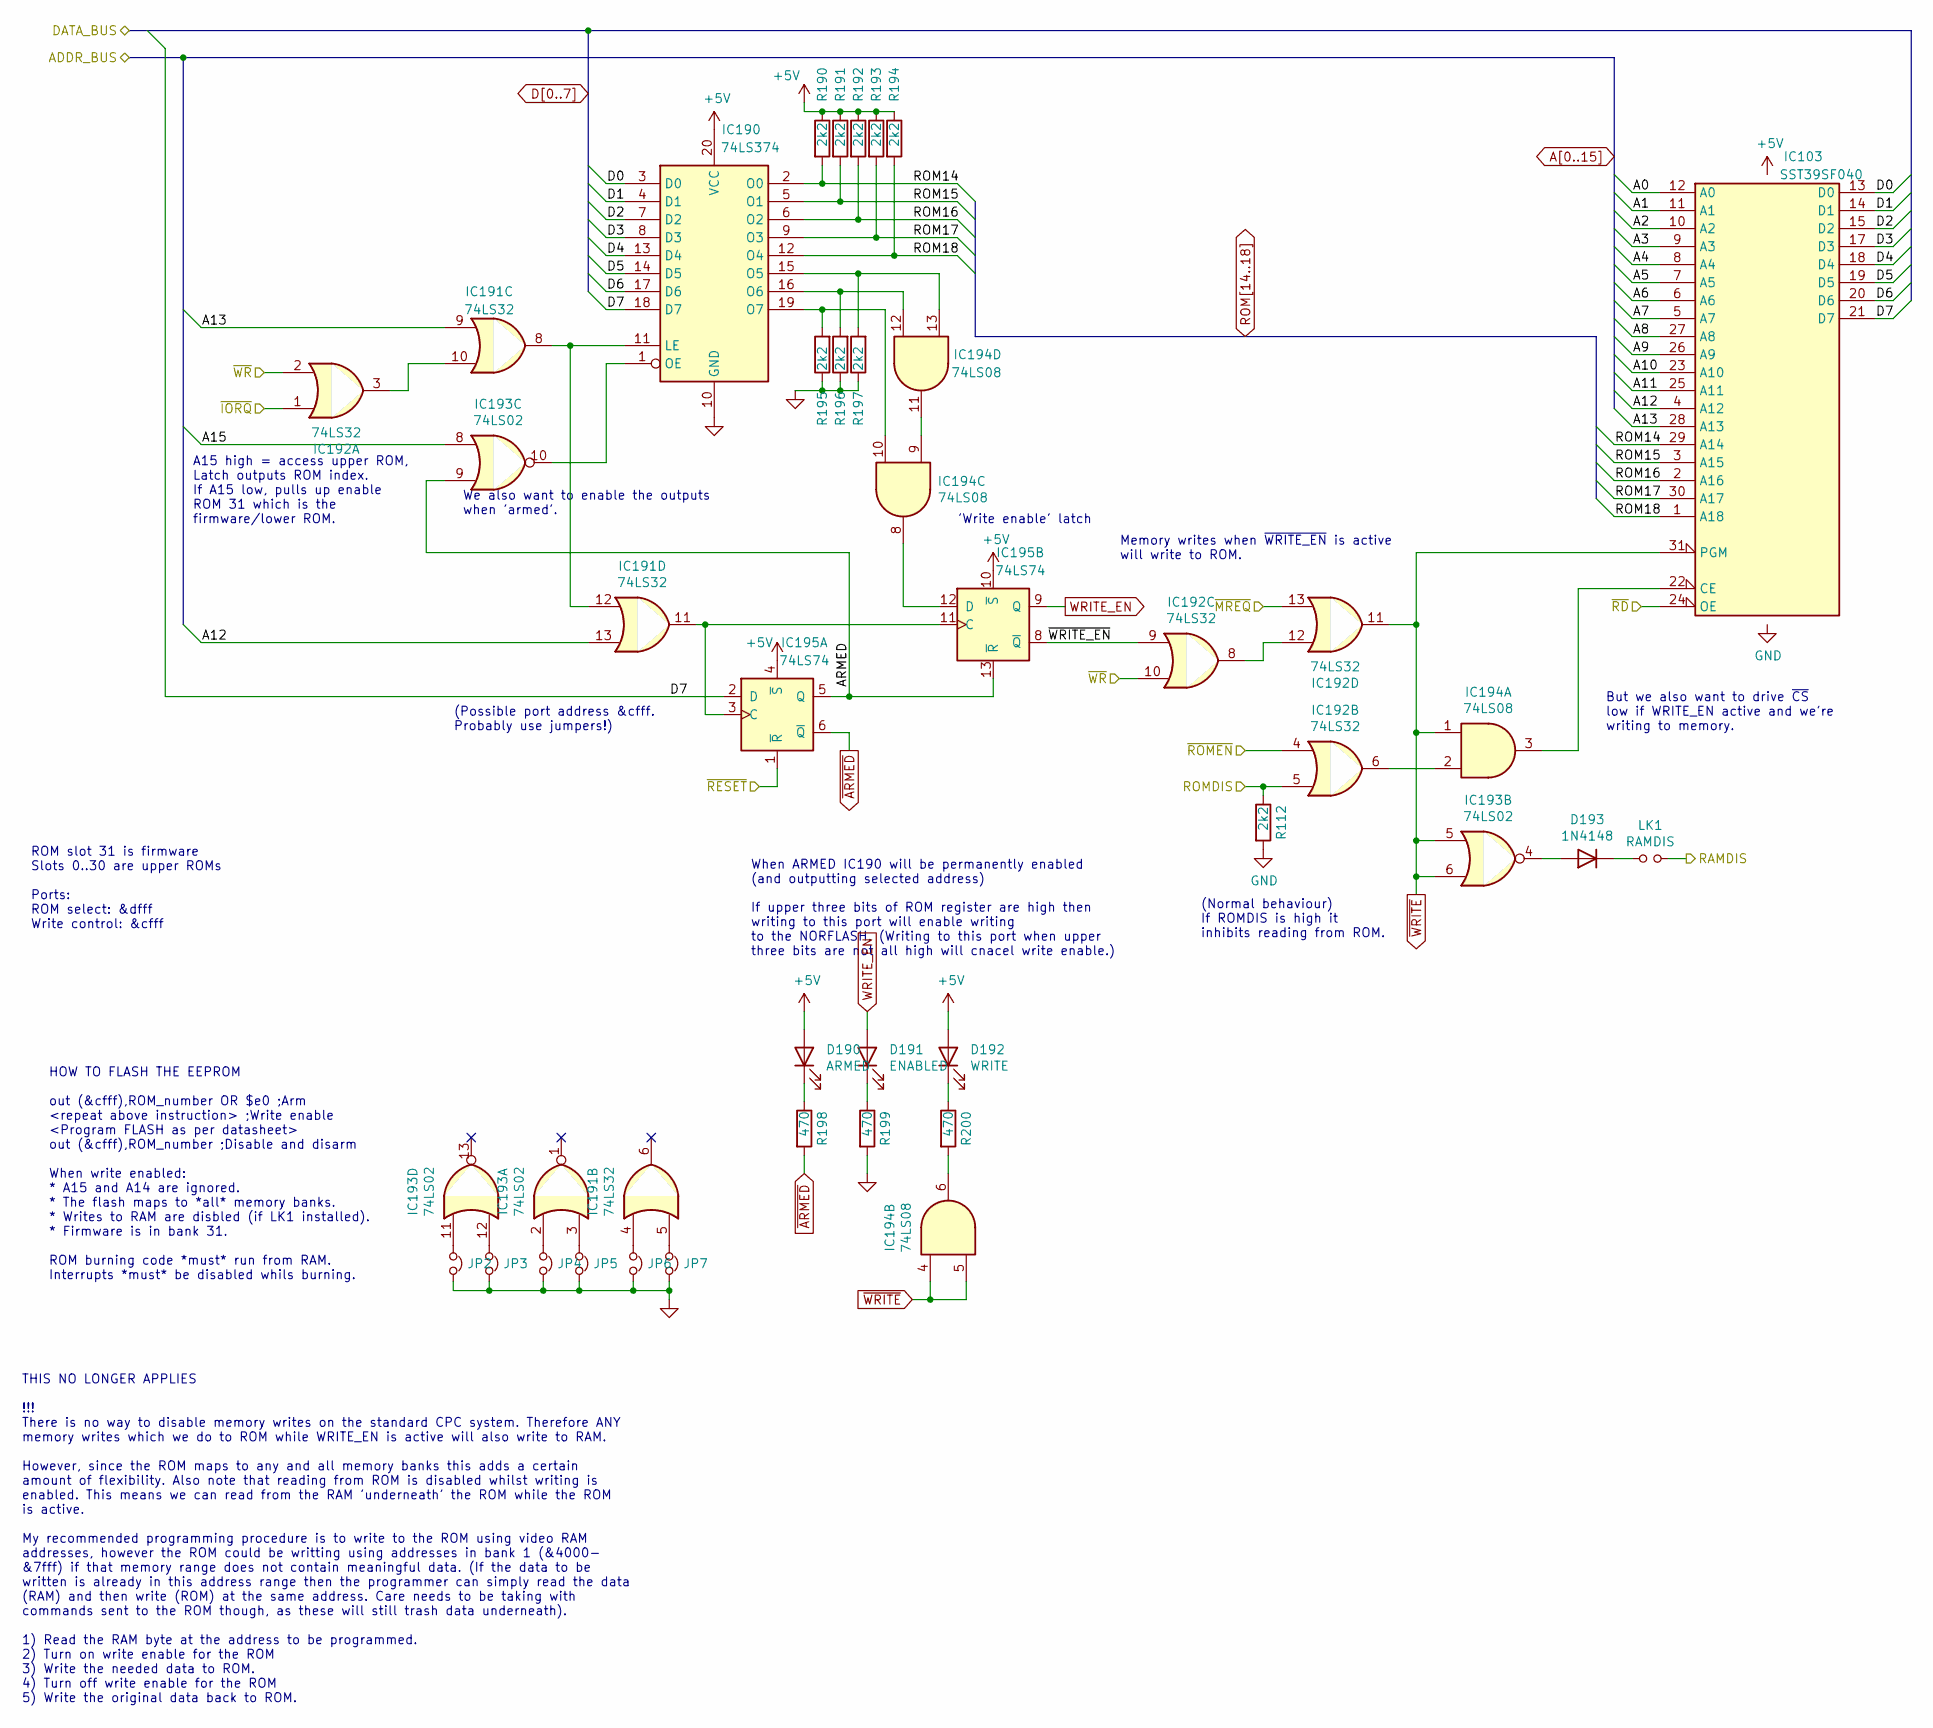
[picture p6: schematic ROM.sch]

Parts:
D190: ARMED; LED_D3.0mm
D191: ENABLED; LED_D3.0mm
D192: WRITE; LED_D3.0mm
D193: 1N4148; D_DO-35_SOD27_P7.62mm_Horizontal
IC103: SST39SF040; DIP_Socket-32_W11.9_W12.7_W15.24_W17.78_W18.5_3M_232-1285-0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
IC190: 74LS374; DIP-20_W7.62mm_Socket
IC191, IC192: 74LS32; DIP-14_W7.62mm_Socket
IC193: 74LS02; DIP-14_W7.62mm_Socket
IC194: 74LS08; DIP-14_W7.62mm_Socket
IC195: 74LS74; DIP-14_W7.62mm_Socket
JP2, JP3, JP4, JP5, JP6, JP7: Jumper_NC_Small; SolderJumper-2_P1.3mm_Bridged_RoundedPad1.0x1.5mm
LK1: RAMDIS; PinHeader_1x02_P2.54mm_Vertical
R112, R190, R191, R192, R193, R194, R195, R196, R197: 2k2; R_Axial_DIN0207_L6.3mm_D2.5mm_P7.62mm_Horizontal
R198, R199, R200: 470; R_Axial_DIN0207_L6.3mm_D2.5mm_P7.62mm_Horizontal

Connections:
+5V: D190.2 (A), D192.2 (A), IC103.32 (VCC), IC190.20 (VCC), IC195.4 (~S), IC195.10 (~S), R190.1, R191.1, R192.1, R193.1, R194.1; also elsewhere on the board
/RAMDIS: LK1.2; also elsewhere on the board
/ROM/ARMED: IC193.9, IC195.5 (Q), IC195.13 (~R)
/ROM/~WRITE_EN: IC192.9, IC195.8 (~Q)
/ROMDIS: IC192.5, R112.1; also elsewhere on the board
/~IORQ: IC192.1; also elsewhere on the board
/~MREQ: IC192.13; also elsewhere on the board
/~RD: IC103.24 (OE); also elsewhere on the board
/~RESET: IC195.1 (~R); also elsewhere on the board
/~ROMEN: IC192.4; also elsewhere on the board
/~WR: IC192.2, IC192.10; also elsewhere on the board
A0: IC103.12 (A0); also elsewhere on the board
A1: IC103.11 (A1); also elsewhere on the board
A2: IC103.10 (A2); also elsewhere on the board
A3: IC103.9 (A3); also elsewhere on the board
A4: IC103.8 (A4); also elsewhere on the board
A5: IC103.7 (A5); also elsewhere on the board
A6: IC103.6 (A6); also elsewhere on the board
A7: IC103.5 (A7); also elsewhere on the board
A8: IC103.27 (A8); also elsewhere on the board
A9: IC103.26 (A9); also elsewhere on the board
A10: IC103.23 (A10); also elsewhere on the board
A11: IC103.25 (A11); also elsewhere on the board
A12: IC103.4 (A12), IC191.13; also elsewhere on the board
A13: IC103.28 (A13), IC191.9; also elsewhere on the board
A15: IC193.8; also elsewhere on the board
D0: IC103.13 (D0), IC190.3 (D0); also elsewhere on the board
D1: IC103.14 (D1), IC190.4 (D1); also elsewhere on the board
D2: IC103.15 (D2), IC190.7 (D2); also elsewhere on the board
D3: IC103.17 (D3), IC190.8 (D3); also elsewhere on the board
D4: IC103.18 (D4), IC190.13 (D4); also elsewhere on the board
D5: IC103.19 (D5), IC190.14 (D5); also elsewhere on the board
D6: IC103.20 (D6), IC190.17 (D6); also elsewhere on the board
D7: IC103.21 (D7), IC190.18 (D7), IC195.2 (D); also elsewhere on the board
GND: IC103.16 (GND), IC190.10 (GND), JP2.2, JP3.2, JP4.2, JP5.2, JP6.2, JP7.2, R112.2, R195.1, R196.1, R197.1, R199.2; also elsewhere on the board
unnamed: D190.1 (K), R198.1
unnamed: D191.1 (K), R199.1
unnamed: D192.1 (K), R200.1
unnamed: D193.1 (K), LK1.1
unnamed: D193.2 (A), IC193.4
unnamed: IC103.22 (CE), IC194.3
unnamed: IC190.1 (OE), IC193.10
unnamed: IC190.11 (LE), IC191.8, IC191.12
unnamed: IC190.15 (O5), IC194.13, R197.2
unnamed: IC190.16 (O6), IC194.12, R196.2
unnamed: IC190.19 (O7), IC194.10, R195.2
unnamed: IC191.4, JP6.1
unnamed: IC191.5, JP7.1
unnamed: IC191.10, IC192.3
unnamed: IC191.11, IC195.3 (C), IC195.11 (C)
unnamed: IC192.6, IC194.2
unnamed: IC192.8, IC192.12
unnamed: IC193.2, JP4.1
unnamed: IC193.3, JP5.1
unnamed: IC193.11, JP2.1
unnamed: IC193.12, JP3.1
unnamed: IC194.6, R200.2
unnamed: IC194.8, IC195.12 (D)
unnamed: IC194.9, IC194.11
ROM14: IC103.29 (A14), IC190.2 (O0), R190.2
ROM15: IC103.3 (A15), IC190.5 (O1), R191.2
ROM16: IC103.2 (A16), IC190.6 (O2), R192.2
ROM17: IC103.30 (A17), IC190.9 (O3), R193.2
ROM18: IC103.1 (A18), IC190.12 (O4), R194.2
WRITE: IC103.31 (PGM), IC192.11, IC193.5, IC193.6, IC194.1, IC194.4, IC194.5
WRITE_EN: D191.2 (A), IC195.9 (Q)
~ARMED: IC195.6 (~Q), R198.2

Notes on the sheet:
A15 high = access upper ROM, Latch outputs ROM index. If A15 low, pulls up enable ROM 31 which is the firmware/lower ROM.
'Write enable' latch
(Possible port address &cfff. Probably use jumpers!)
If upper three bits of ROM register are high then writing to this port will enable writing to the NORFLASH. (Writing to this port when upper three bits are not all high will cnacel write enable.)
Memory writes when ~WRITE_EN~ is active will write to ROM.
(Normal behaviour) If ROMDIS is high it inhibits reading from ROM.
But we also want to drive ~CS~ low if WRITE_EN active and we're writing to memory.
THIS NO LONGER APPLIES !!! There is no way to disable memory writes on the standard CPC system. Therefore ANY memory writes which we do to ROM while WRITE_EN is active will also write to RAM. However, since the ROM maps to any and all memory banks this adds a certain amount of flexibility. Also not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
HOW TO FLASH THE EEPROM out (&cfff),ROM_number OR $e0 ;Arm <repeat above instruction> ;Write enable <Program FLASH as per datasheet> out (&cfff),ROM_number ;Disable and disarm When write enabled: * A15 and A14 are ignored. * The flash maps to *all* memory banks. * Writes to RAM are disbled (if LK1 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
We also want to enable the outputs when 'armed'.
When ARMED IC190 will be permanently enabled (and outputting selected address)
ROM slot 31 is firmware Slots 0..30 are upper ROMs Ports: ROM select: &dfff Write control: &cfff

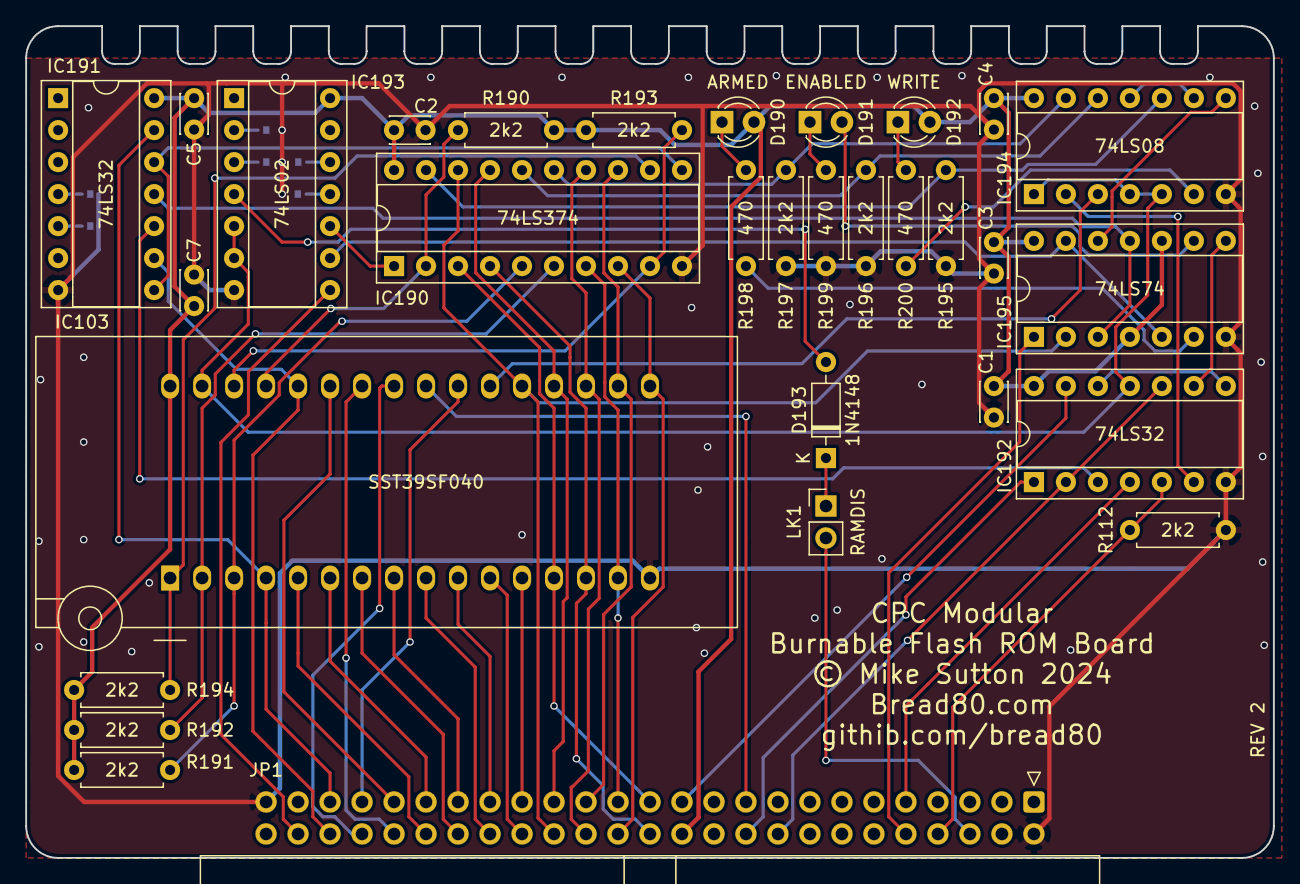
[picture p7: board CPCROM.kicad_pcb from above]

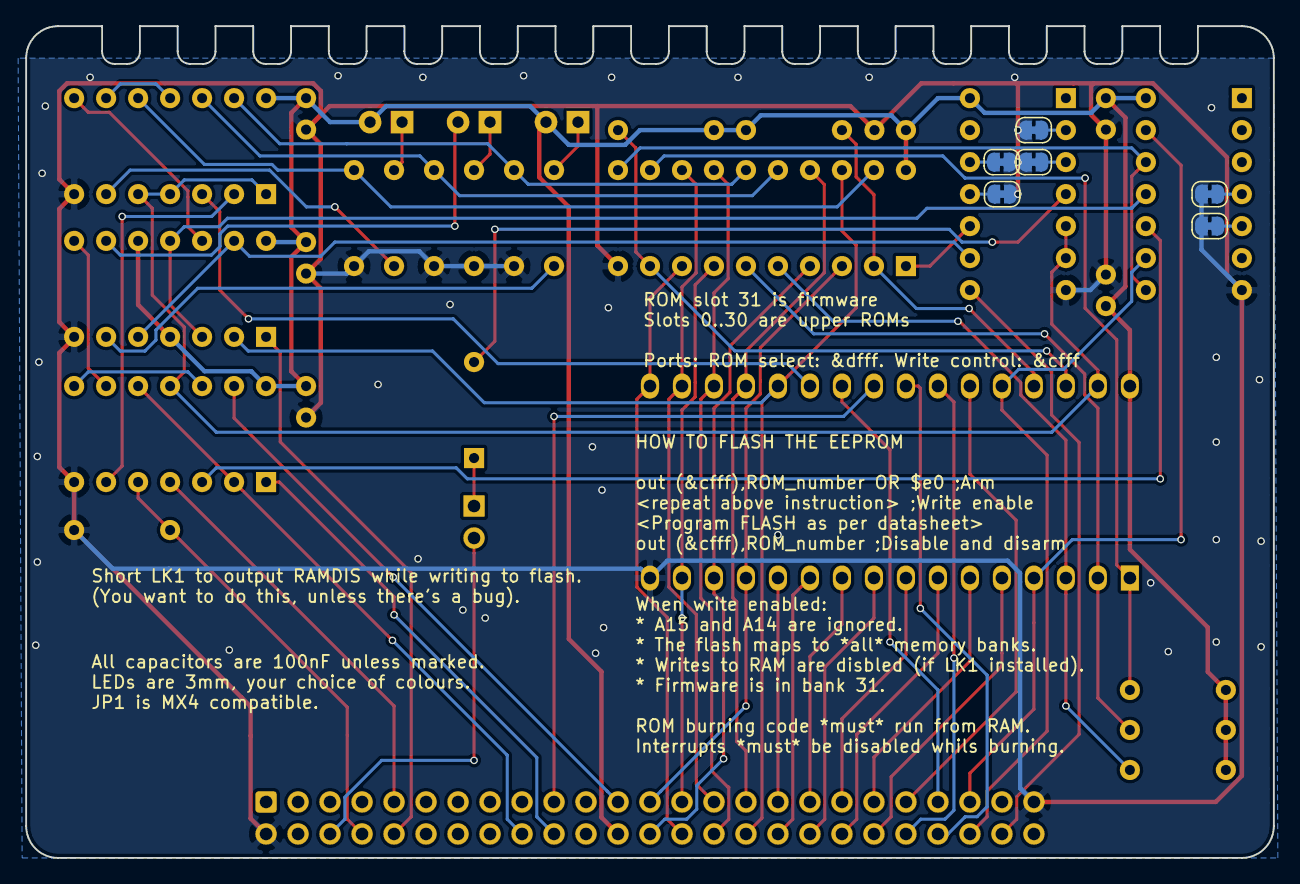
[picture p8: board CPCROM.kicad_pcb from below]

Board: 2 copper layers, 99.1 x 66.0 mm, 37 parts (6 on the bottom side), 67 nets.

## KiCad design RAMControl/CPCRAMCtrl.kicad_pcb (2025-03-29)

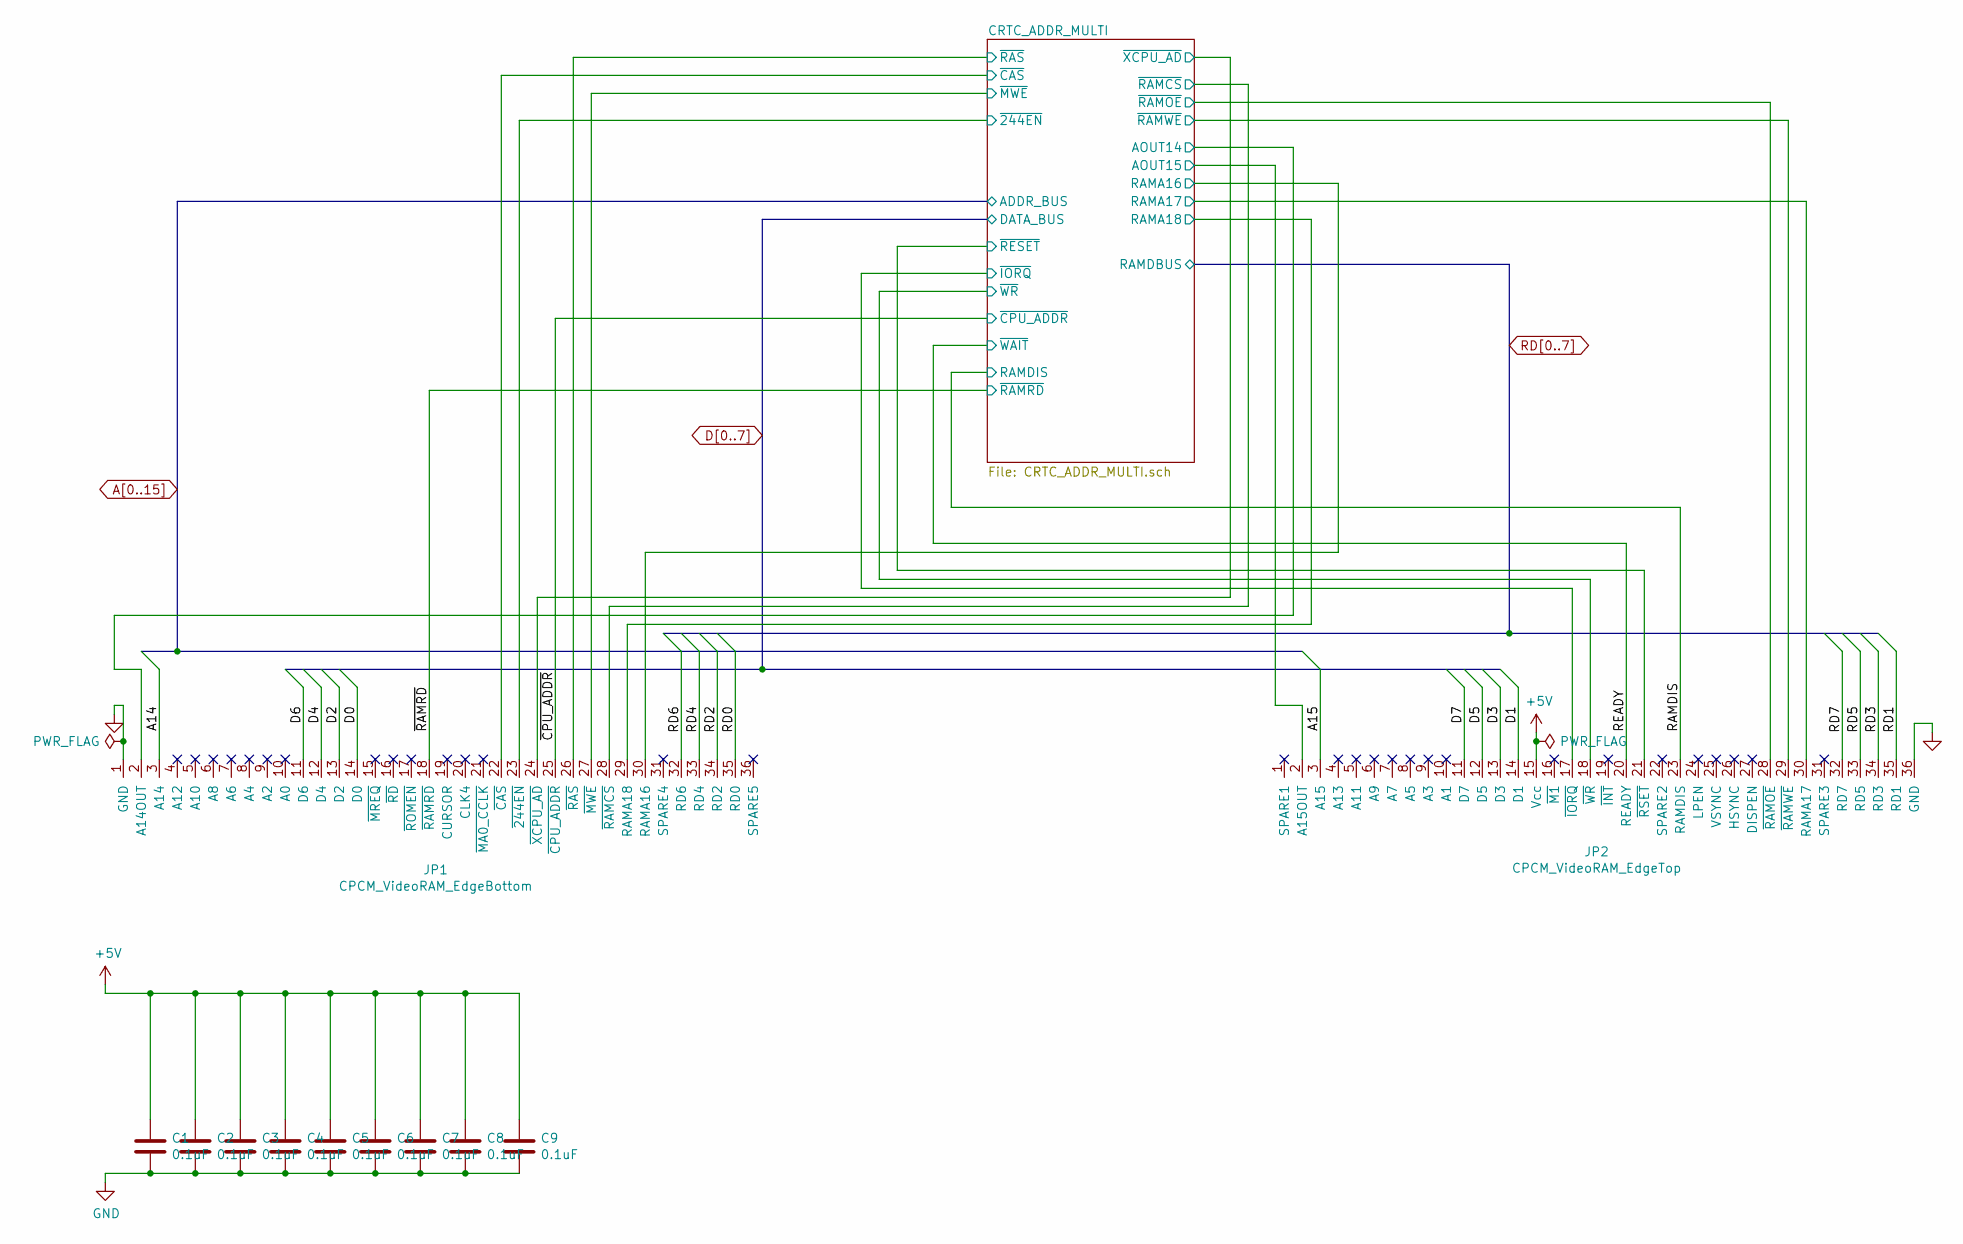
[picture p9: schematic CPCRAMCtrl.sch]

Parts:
C1, C2, C3, C4, C5, C6, C7, C8, C9: 0.1uF; C_Disc_D3.0mm_W2.0mm_P2.50mm
JP1: CPCM_VideoRAM_EdgeBottom; Edge36_2.54PS
JP2: CPCM_VideoRAM_EdgeTop; Edge36_2.54PS

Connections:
+5V: C1.1, C2.1, C3.1, C4.1, C5.1, C6.1, C7.1, C8.1, C9.1, JP2.15 (Vcc); also elsewhere on the board
/CRTC_ADDR_MULTI/AOUT14: JP1.2 (A14OUT); also elsewhere on the board
/CRTC_ADDR_MULTI/AOUT15: JP2.2 (A15OUT); also elsewhere on the board
/CRTC_ADDR_MULTI/RAMA16: JP1.30 (RAMA16); also elsewhere on the board
/CRTC_ADDR_MULTI/RAMA17: JP2.30 (RAMA17); also elsewhere on the board
/CRTC_ADDR_MULTI/RAMA18: JP1.29 (RAMA18); also elsewhere on the board
/CRTC_ADDR_MULTI/~244EN: JP1.23 (~244EN); also elsewhere on the board
/CRTC_ADDR_MULTI/~CAS: JP1.22 (~CAS); also elsewhere on the board
/CRTC_ADDR_MULTI/~IORQ: JP2.17 (~IORQ); also elsewhere on the board
/CRTC_ADDR_MULTI/~MWE: JP1.27 (~MWE); also elsewhere on the board
/CRTC_ADDR_MULTI/~RAMCS: JP1.28 (~RAMCS); also elsewhere on the board
/CRTC_ADDR_MULTI/~RAMOE: JP2.28 (~RAMOE); also elsewhere on the board
/CRTC_ADDR_MULTI/~RAMWE: JP2.29 (~RAMWE); also elsewhere on the board
/CRTC_ADDR_MULTI/~RAS: JP1.26 (~RAS); also elsewhere on the board
/CRTC_ADDR_MULTI/~RESET: JP2.21 (~RSET); also elsewhere on the board
/CRTC_ADDR_MULTI/~WR: JP2.18 (~WR); also elsewhere on the board
/CRTC_ADDR_MULTI/~XCPU_AD: JP1.24 (~XCPU_AD); also elsewhere on the board
/RAMDIS: JP2.23 (RAMDIS); also elsewhere on the board
/READY: JP2.20 (READY); also elsewhere on the board
/~CPU_ADDR: JP1.25 (~CPU_ADDR); also elsewhere on the board
/~RAMRD: JP1.18 (~RAMRD); also elsewhere on the board
A14: JP1.3 (A14); also elsewhere on the board
A15: JP2.3 (A15); also elsewhere on the board
D0: JP1.14 (D0); also elsewhere on the board
D1: JP2.14 (D1); also elsewhere on the board
D2: JP1.13 (D2); also elsewhere on the board
D3: JP2.13 (D3); also elsewhere on the board
D4: JP1.12 (D4); also elsewhere on the board
D5: JP2.12 (D5); also elsewhere on the board
D6: JP1.11 (D6); also elsewhere on the board
D7: JP2.11 (D7); also elsewhere on the board
GND: C1.2, C2.2, C3.2, C4.2, C5.2, C6.2, C7.2, C8.2, C9.2, JP1.1 (GND), JP2.36 (GND); also elsewhere on the board
RD0: JP1.35 (RD0); also elsewhere on the board
RD1: JP2.35 (RD1); also elsewhere on the board
RD2: JP1.34 (RD2); also elsewhere on the board
RD3: JP2.34 (RD3); also elsewhere on the board
RD4: JP1.33 (RD4); also elsewhere on the board
RD5: JP2.33 (RD5); also elsewhere on the board
RD6: JP1.32 (RD6); also elsewhere on the board
RD7: JP2.32 (RD7); also elsewhere on the board

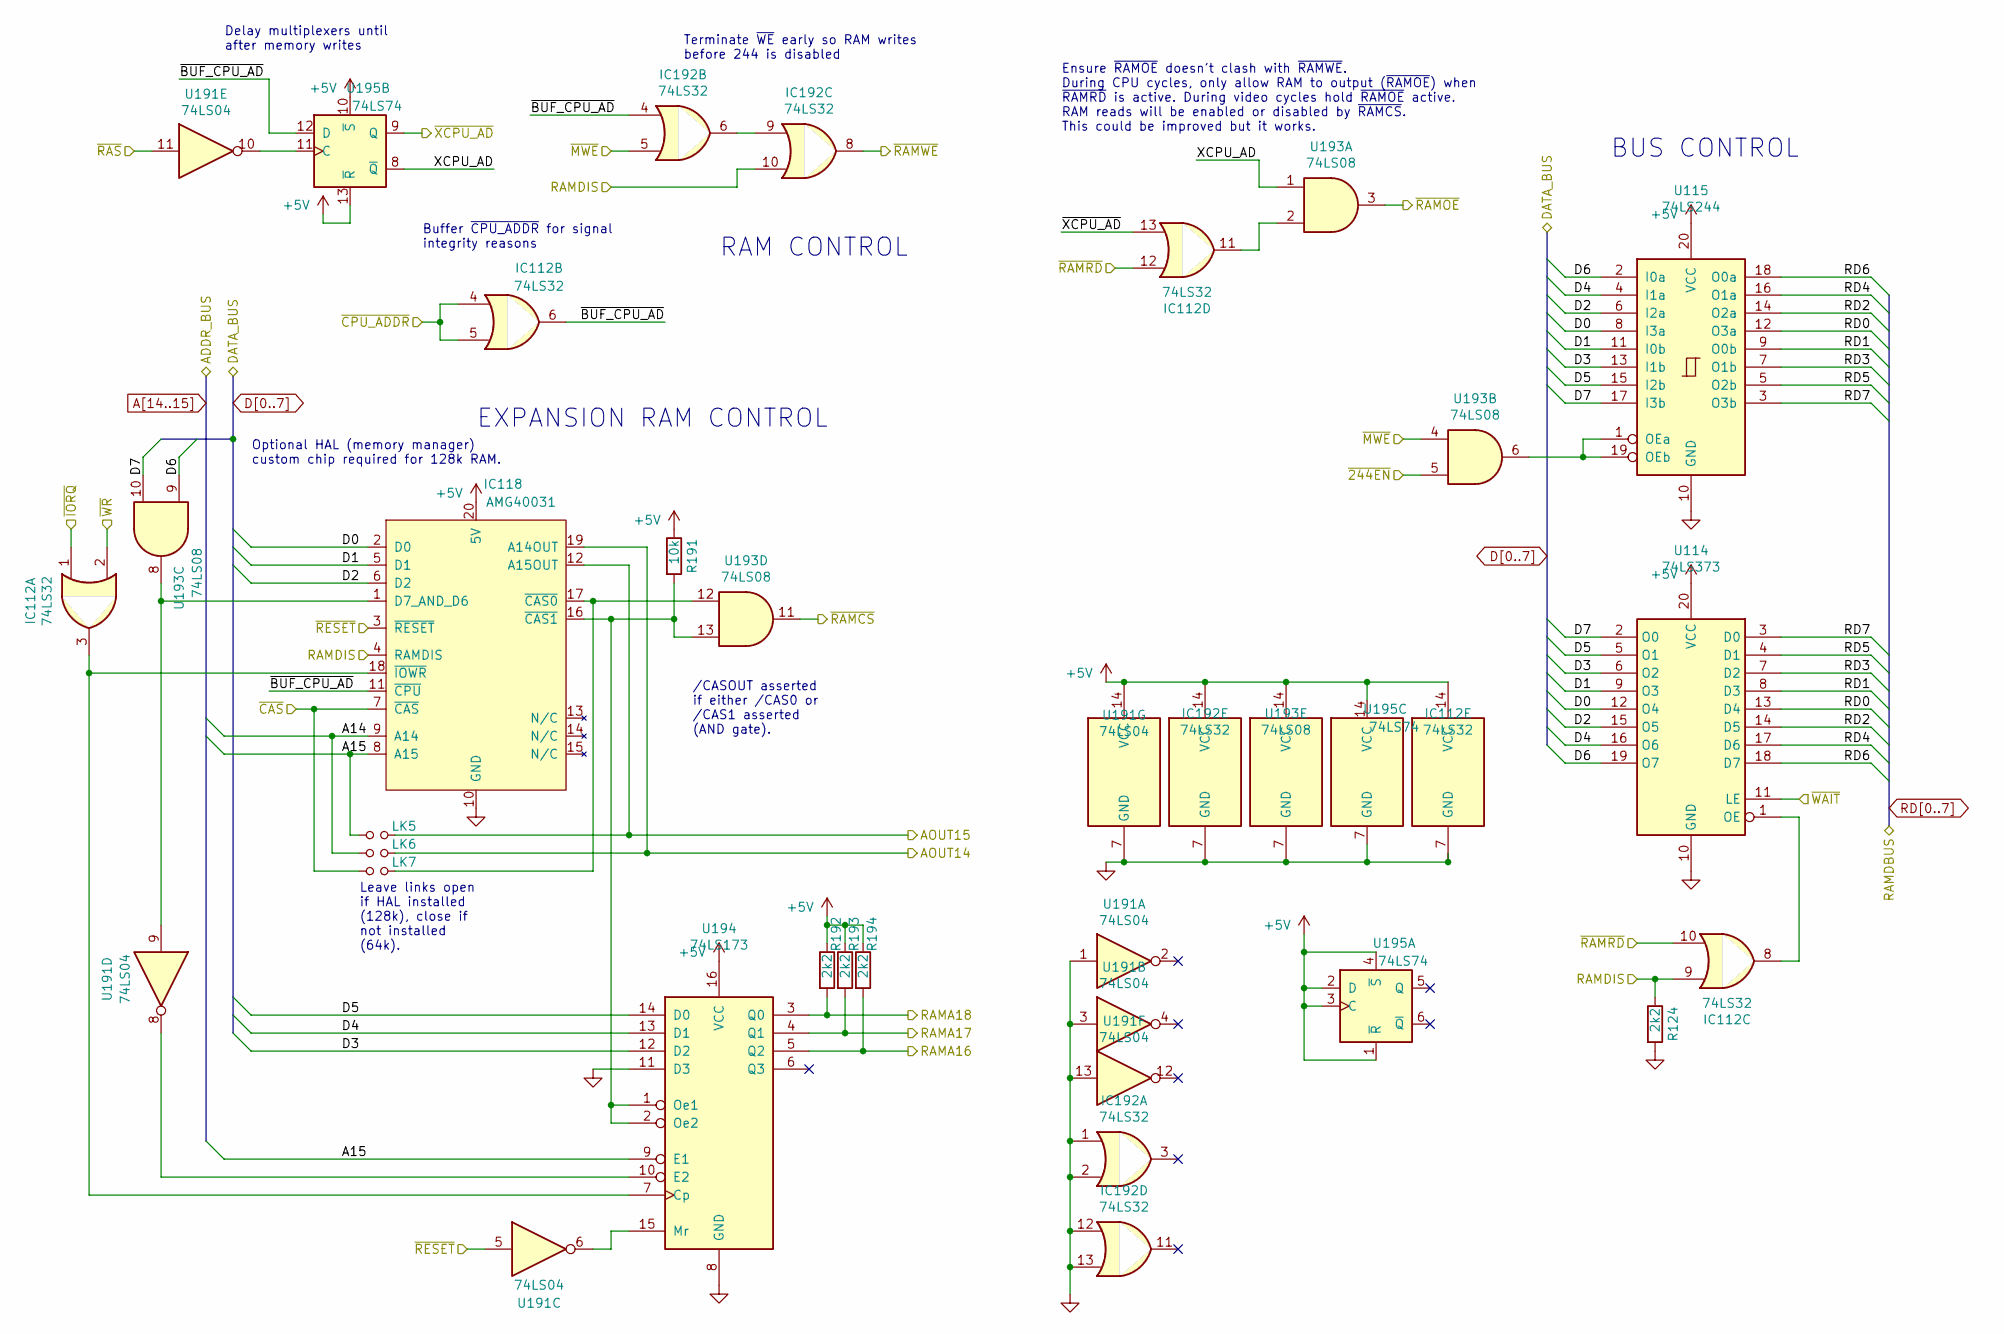
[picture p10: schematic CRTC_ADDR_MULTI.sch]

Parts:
IC112, IC192: 74LS32; DIP-14_W7.62mm_Socket
IC118: AMG40031; DIP-20_W7.62mm
LK5, LK6, LK7: Jumper_NO_Small; PinHeader_1x02_P2.54mm_Vertical
R124, R192, R193, R194: 2k2; R_Axial_DIN0207_L6.3mm_D2.5mm_P7.62mm_Horizontal
R191: 10k; R_Axial_DIN0207_L6.3mm_D2.5mm_P7.62mm_Horizontal
U114: 74LS373; DIP-20_W7.62mm_Socket
U115: 74LS244; DIP-20_W7.62mm_Socket
U191: 74LS04; DIP-14_W7.62mm_Socket
U193: 74LS08; DIP-14_W7.62mm_Socket
U194: 74LS173; DIP-16_W7.62mm_Socket
U195: 74LS74; DIP-14_W7.62mm_Socket

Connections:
+5V: IC112.14 (VCC), IC118.20 (5V), IC192.14 (VCC), R191.1, R192.1, R193.1, R194.1, U114.20 (VCC), U115.20 (VCC), U191.14 (VCC), U193.14 (VCC), U194.16 (VCC), U195.1 (~R), U195.2 (D), U195.3 (C), U195.4 (~S), U195.10 (~S), U195.13 (~R), U195.14 (VCC); also elsewhere on the board
/CRTC_ADDR_MULTI/AOUT14: IC118.19 (A14OUT), LK6.2; also elsewhere on the board
/CRTC_ADDR_MULTI/AOUT15: IC118.12 (A15OUT), LK5.2; also elsewhere on the board
/CRTC_ADDR_MULTI/RAMA16: R194.2, U194.5 (Q2); also elsewhere on the board
/CRTC_ADDR_MULTI/RAMA17: R193.2, U194.4 (Q1); also elsewhere on the board
/CRTC_ADDR_MULTI/RAMA18: R192.2, U194.3 (Q0); also elsewhere on the board
/CRTC_ADDR_MULTI/XCPU_AD: U193.1, U195.8 (~Q)
/CRTC_ADDR_MULTI/~244EN: U193.5; also elsewhere on the board
/CRTC_ADDR_MULTI/~BUF_CPU_AD: IC112.6, IC118.11 (~CPU), IC192.4, U195.12 (D)
/CRTC_ADDR_MULTI/~CAS: IC118.7 (~CAS), LK7.1; also elsewhere on the board
/CRTC_ADDR_MULTI/~IORQ: IC112.1; also elsewhere on the board
/CRTC_ADDR_MULTI/~MWE: IC192.5, U193.4; also elsewhere on the board
/CRTC_ADDR_MULTI/~RAMCS: U193.11; also elsewhere on the board
/CRTC_ADDR_MULTI/~RAMOE: U193.3; also elsewhere on the board
/CRTC_ADDR_MULTI/~RAMWE: IC192.8; also elsewhere on the board
/CRTC_ADDR_MULTI/~RAS: U191.11; also elsewhere on the board
/CRTC_ADDR_MULTI/~RESET: IC118.3 (~RESET), U191.5; also elsewhere on the board
/CRTC_ADDR_MULTI/~WR: IC112.2; also elsewhere on the board
/CRTC_ADDR_MULTI/~XCPU_AD: IC112.13, U195.9 (Q); also elsewhere on the board
/RAMDIS: IC112.9, IC118.4 (RAMDIS), IC192.10, R124.1; also elsewhere on the board
/READY: U114.11 (LE); also elsewhere on the board
/~CPU_ADDR: IC112.4, IC112.5; also elsewhere on the board
/~RAMRD: IC112.10, IC112.12; also elsewhere on the board
A14: IC118.9 (A14), LK6.1; also elsewhere on the board
A15: IC118.8 (A15), LK5.1, U194.9 (E1); also elsewhere on the board
D0: IC118.2 (D0), U114.12 (O4), U115.8 (I3a); also elsewhere on the board
D1: IC118.5 (D1), U114.9 (O3), U115.11 (I0b); also elsewhere on the board
D2: IC118.6 (D2), U114.15 (O5), U115.6 (I2a); also elsewhere on the board
D3: U114.6 (O2), U115.13 (I1b), U194.12 (D2); also elsewhere on the board
D4: U114.16 (O6), U115.4 (I1a), U194.13 (D1); also elsewhere on the board
D5: U114.5 (O1), U115.15 (I2b), U194.14 (D0); also elsewhere on the board
D6: U114.19 (O7), U115.2 (I0a), U193.9; also elsewhere on the board
D7: U114.2 (O0), U115.17 (I3b), U193.10; also elsewhere on the board
GND: IC112.7 (GND), IC118.10 (GND), IC192.1, IC192.2, IC192.7 (GND), IC192.12, IC192.13, R124.2, U114.10 (GND), U115.10 (GND), U191.1, U191.3, U191.7 (GND), U191.13, U193.7 (GND), U194.8 (GND), U194.11 (D3), U195.7 (GND); also elsewhere on the board
unnamed: IC112.3, IC118.18 (~IOWR), U194.7 (Cp)
unnamed: IC112.8, U114.1 (OE)
unnamed: IC112.11, U193.2
unnamed: IC118.1 (D7_AND_D6), U191.9, U193.8
unnamed: IC118.16 (~CAS1), R191.2, U193.13, U194.1 (Oe1), U194.2 (Oe2)
unnamed: IC118.17 (~CAS0), LK7.2, U193.12
unnamed: IC192.6, IC192.9
unnamed: U115.1 (OEa), U115.19 (OEb), U193.6
unnamed: U191.6, U194.15 (Mr)
unnamed: U191.8, U194.10 (E2)
unnamed: U191.10, U195.11 (C)
RD0: U114.13 (D4), U115.12 (O3a); also elsewhere on the board
RD1: U114.8 (D3), U115.9 (O0b); also elsewhere on the board
RD2: U114.14 (D5), U115.14 (O2a); also elsewhere on the board
RD3: U114.7 (D2), U115.7 (O1b); also elsewhere on the board
RD4: U114.17 (D6), U115.16 (O1a); also elsewhere on the board
RD5: U114.4 (D1), U115.5 (O2b); also elsewhere on the board
RD6: U114.18 (D7), U115.18 (O0a); also elsewhere on the board
RD7: U114.3 (D0), U115.3 (O3b); also elsewhere on the board

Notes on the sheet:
Leave links open if HAL installed (128k), close if not installed (64k).
Optional HAL (memory manager) custom chip required for 128k RAM.
/CASOUT asserted if either /CAS0 or /CAS1 asserted (AND gate).
BUS CONTROL
RAM CONTROL
EXPANSION RAM CONTROL
Buffer ~CPU_ADDR~ for signal integrity reasons
Delay multiplexers until after memory writes
Terminate ~WE~ early so RAM writes before 244 is disabled
Ensure ~RAMOE~ doesn't clash with ~RAMWE~. During CPU cycles, only allow RAM to output (~RAMOE~) when ~RAMRD~ is active. During video cycles hold ~RAMOE~ active. RAM reads will be enabled or disabled by ~RAMCS~. This could be improved but it works.

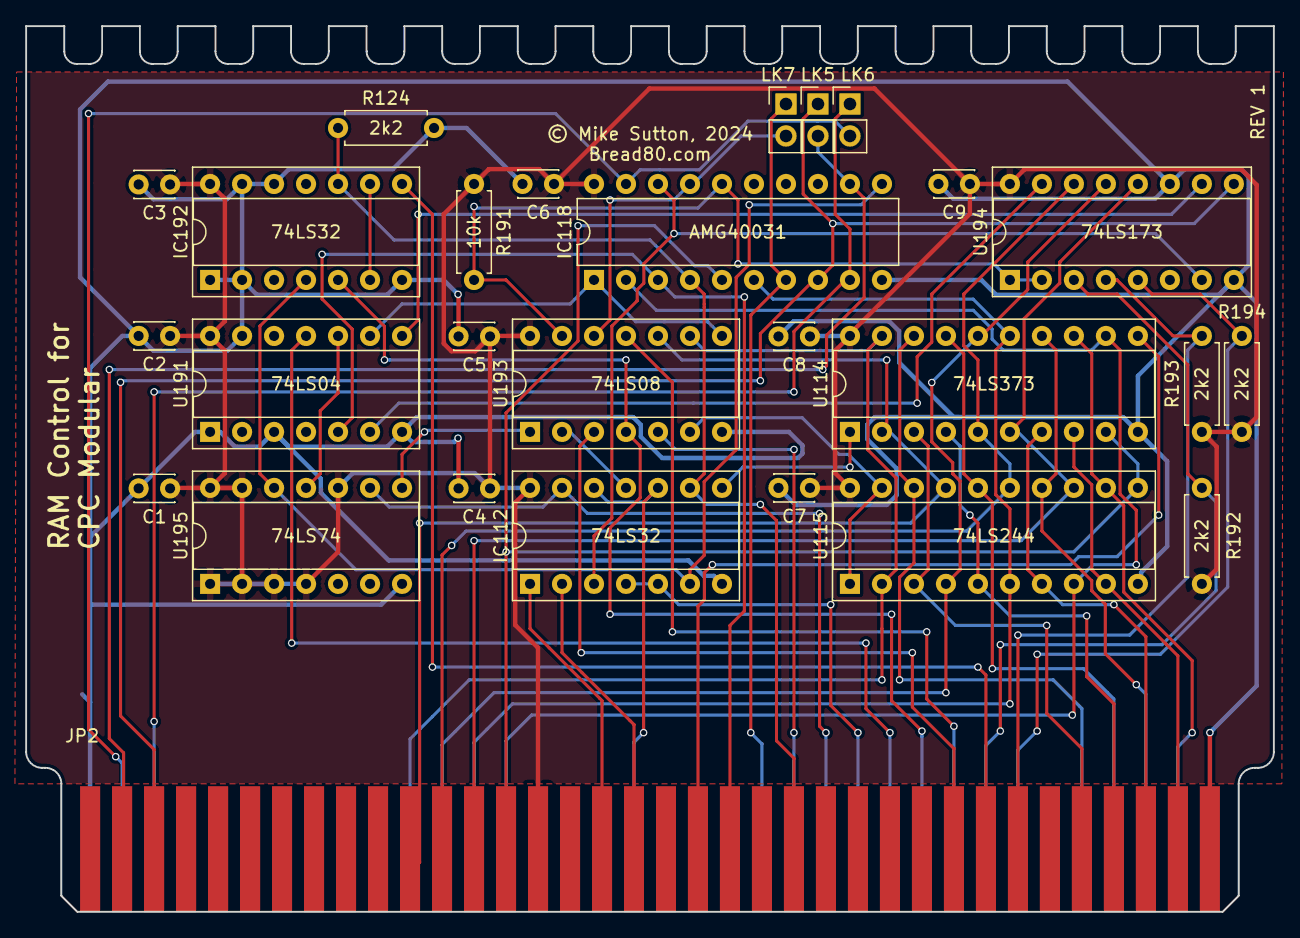
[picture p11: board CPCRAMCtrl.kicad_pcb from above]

Board: 2 copper layers, 99.1 x 70.3 mm, 28 parts (1 on the bottom side), 53 nets.

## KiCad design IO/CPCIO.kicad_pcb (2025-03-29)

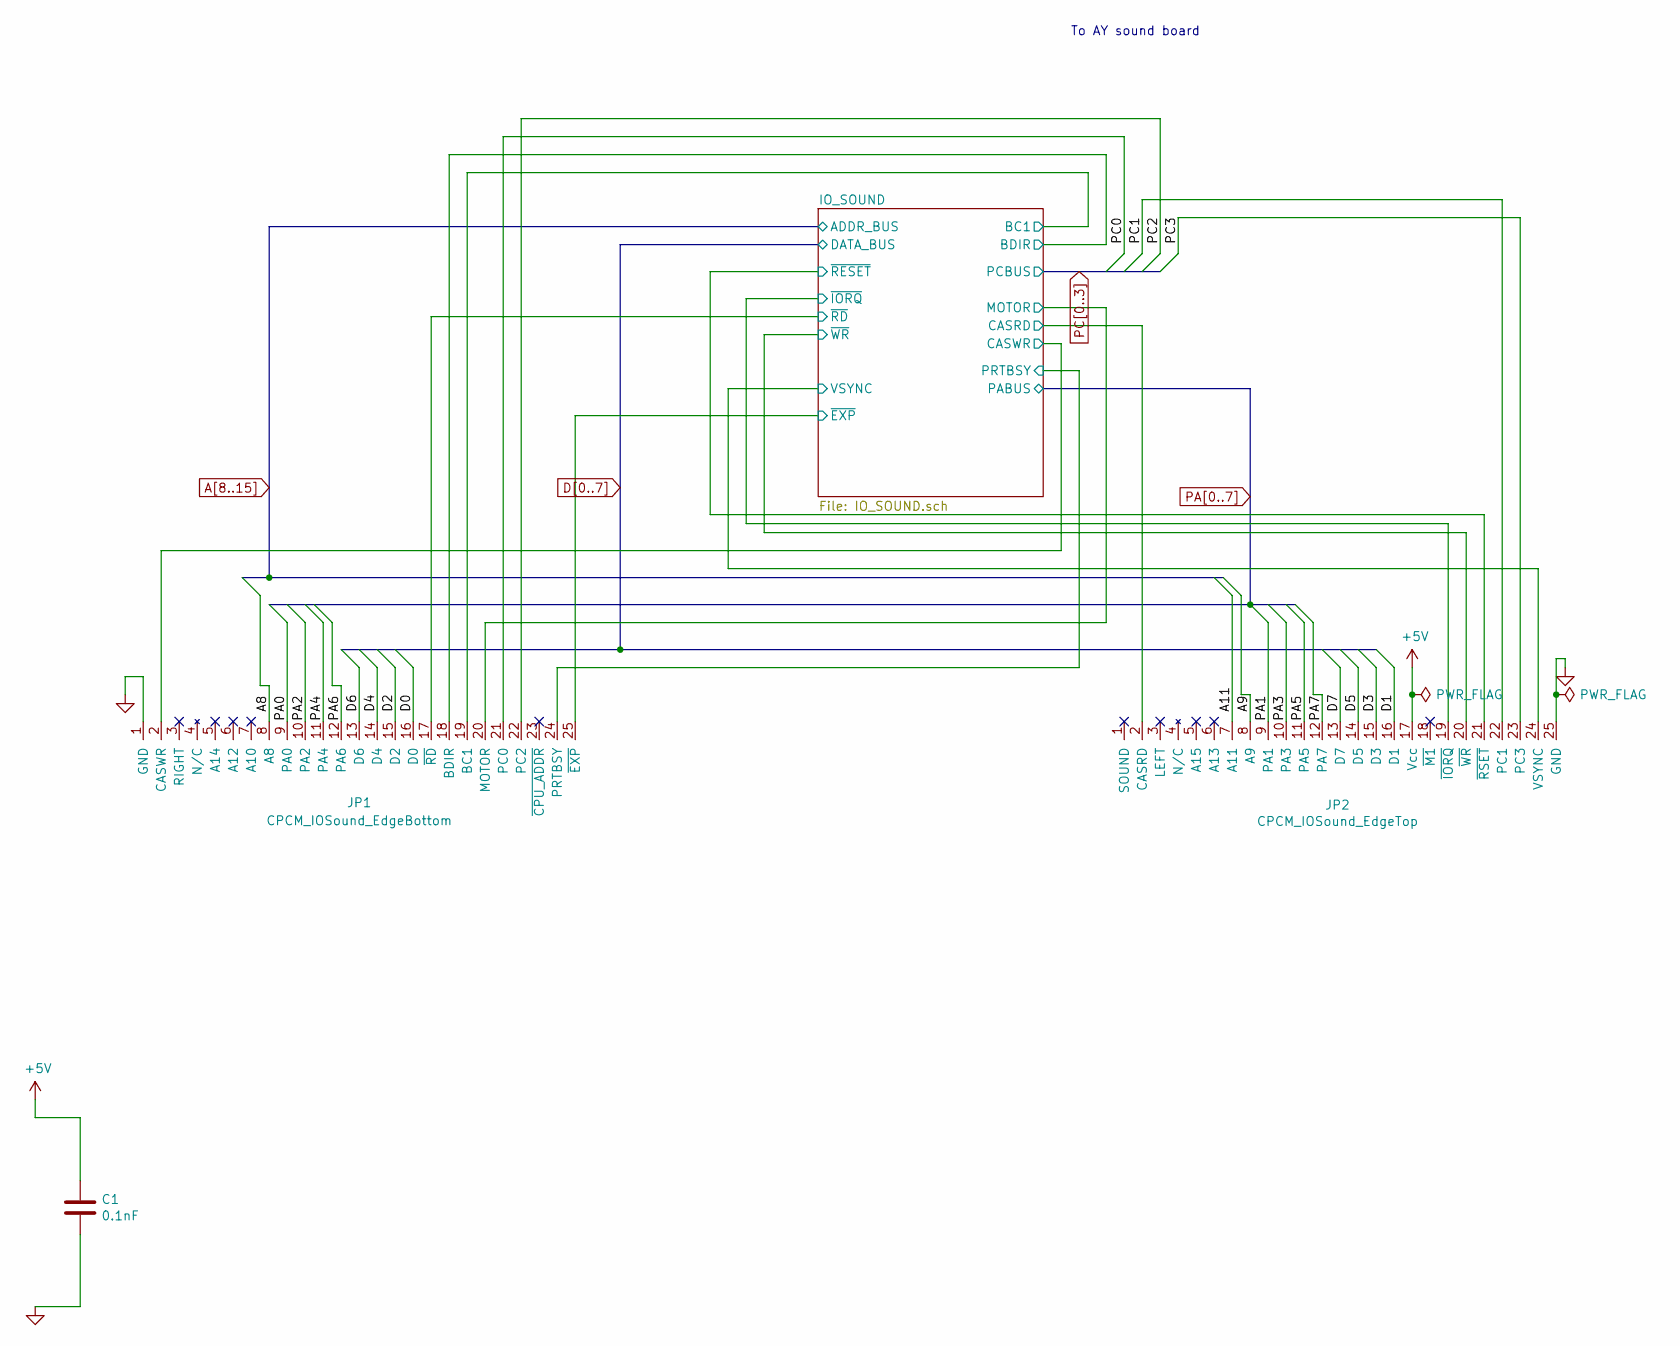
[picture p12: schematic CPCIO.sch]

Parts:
C1: 0.1nF; C_Disc_D3.0mm_W2.0mm_P2.50mm
JP1: CPCM_IOSound_EdgeBottom; Edge25_2.54PS
JP2: CPCM_IOSound_EdgeTop; Edge25_2.54PS

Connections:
+5V: C1.1, JP2.17 (Vcc); also elsewhere on the board
/IO_SOUND/BC1: JP1.19 (BC1); also elsewhere on the board
/IO_SOUND/BDIR: JP1.18 (BDIR); also elsewhere on the board
/IO_SOUND/CASRD: JP2.2 (CASRD); also elsewhere on the board
/IO_SOUND/CASWR: JP1.2 (CASWR); also elsewhere on the board
/IO_SOUND/MOTOR: JP1.20 (MOTOR); also elsewhere on the board
/IO_SOUND/PRTBSY: JP1.24 (PRTBSY); also elsewhere on the board
/IO_SOUND/VSYNC: JP2.24 (VSYNC); also elsewhere on the board
/IO_SOUND/~EXP: JP1.25 (~EXP); also elsewhere on the board
/IO_SOUND/~IORQ: JP2.19 (~IORQ); also elsewhere on the board
/IO_SOUND/~RD: JP1.17 (~RD); also elsewhere on the board
/IO_SOUND/~RESET: JP2.21 (~RSET); also elsewhere on the board
/IO_SOUND/~WR: JP2.20 (~WR); also elsewhere on the board
A8: JP1.8 (A8); also elsewhere on the board
A9: JP2.8 (A9); also elsewhere on the board
A11: JP2.7 (A11); also elsewhere on the board
D0: JP1.16 (D0); also elsewhere on the board
D1: JP2.16 (D1); also elsewhere on the board
D2: JP1.15 (D2); also elsewhere on the board
D3: JP2.15 (D3); also elsewhere on the board
D4: JP1.14 (D4); also elsewhere on the board
D5: JP2.14 (D5); also elsewhere on the board
D6: JP1.13 (D6); also elsewhere on the board
D7: JP2.13 (D7); also elsewhere on the board
GND: C1.2, JP1.1 (GND), JP2.25 (GND); also elsewhere on the board
PA0: JP1.9 (PA0); also elsewhere on the board
PA1: JP2.9 (PA1); also elsewhere on the board
PA2: JP1.10 (PA2); also elsewhere on the board
PA3: JP2.10 (PA3); also elsewhere on the board
PA4: JP1.11 (PA4); also elsewhere on the board
PA5: JP2.11 (PA5); also elsewhere on the board
PA6: JP1.12 (PA6); also elsewhere on the board
PA7: JP2.12 (PA7); also elsewhere on the board
PC0: JP1.21 (PC0); also elsewhere on the board
PC1: JP2.22 (PC1); also elsewhere on the board
PC2: JP1.22 (PC2); also elsewhere on the board
PC3: JP2.23 (PC3); also elsewhere on the board

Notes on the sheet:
To AY sound board

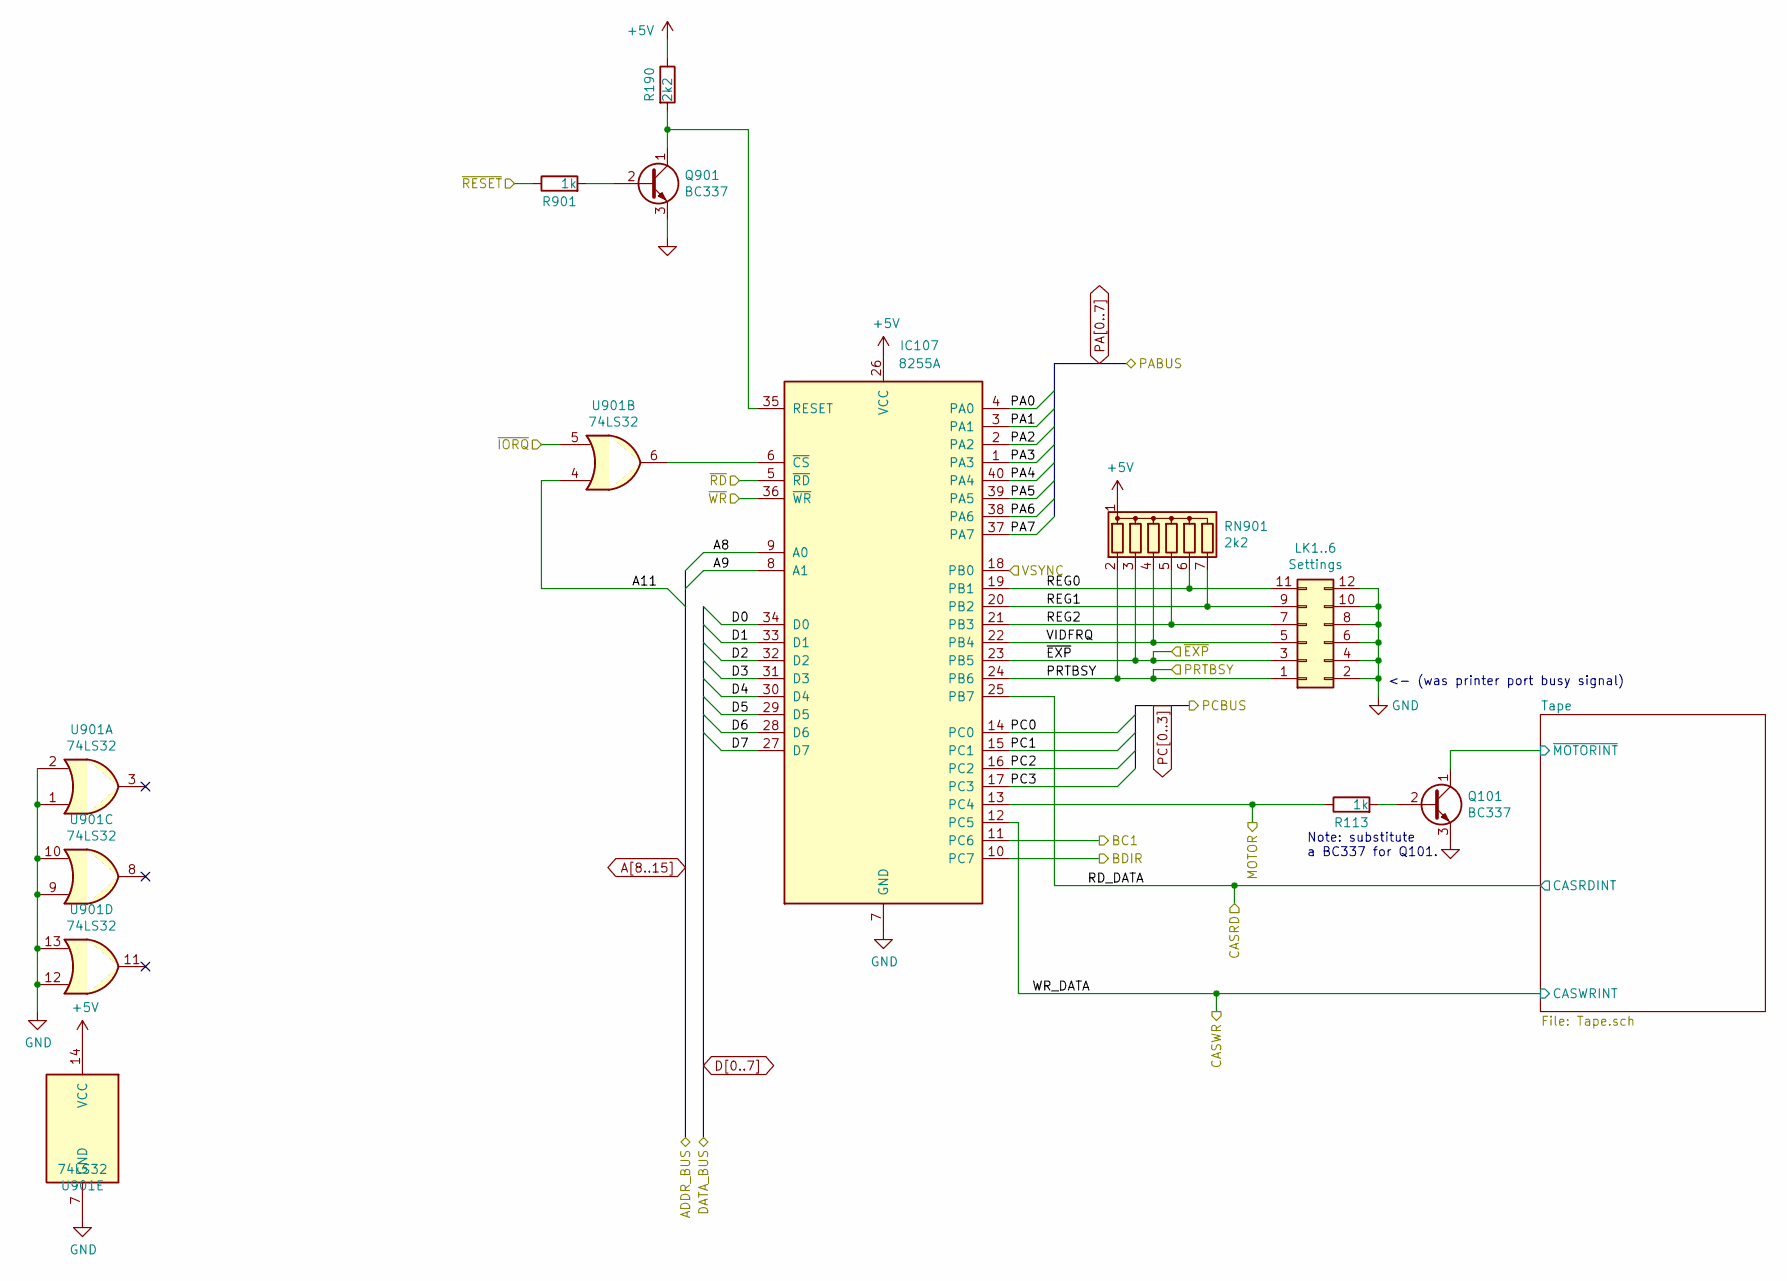
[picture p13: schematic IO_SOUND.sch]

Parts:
IC107: 8255A; DIP-40_W15.24mm_Socket
LK1..6: Settings; PinHeader_2x06_P2.54mm_Vertical
Q101, Q901: BC337; TO-92_HandSolder
R113, R901: 1k; R_Axial_DIN0207_L6.3mm_D2.5mm_P7.62mm_Horizontal
R190: 2k2; R_Axial_DIN0207_L6.3mm_D2.5mm_P7.62mm_Horizontal
RN901: 2k2; R_Array_SIP7
U901: 74LS32; DIP-14_W7.62mm_Socket

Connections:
+5V: IC107.26 (VCC), R190.1, RN901.1 (common), U901.14 (VCC); also elsewhere on the board
/IO_SOUND/BC1: IC107.11 (PC6); also elsewhere on the board
/IO_SOUND/BDIR: IC107.10 (PC7); also elsewhere on the board
/IO_SOUND/CASRD: IC107.25 (PB7); also elsewhere on the board
/IO_SOUND/CASWR: IC107.12 (PC5); also elsewhere on the board
/IO_SOUND/MOTOR: IC107.13 (PC4), R113.1; also elsewhere on the board
/IO_SOUND/PRTBSY: IC107.24 (PB6), LK1..6.1, RN901.2 (R1); also elsewhere on the board
/IO_SOUND/REG0: IC107.19 (PB1), LK1..6.11, RN901.6 (R5)
/IO_SOUND/REG1: IC107.20 (PB2), LK1..6.9, RN901.7 (R6)
/IO_SOUND/REG2: IC107.21 (PB3), LK1..6.7, RN901.5 (R4)
/IO_SOUND/Tape/~MOTORINT: Q101.1 (C); also elsewhere on the board
/IO_SOUND/VIDFRQ: IC107.22 (PB4), LK1..6.5, RN901.4 (R3)
/IO_SOUND/VSYNC: IC107.18 (PB0); also elsewhere on the board
/IO_SOUND/~EXP: IC107.23 (PB5), LK1..6.3, RN901.3 (R2); also elsewhere on the board
/IO_SOUND/~IORQ: U901.5; also elsewhere on the board
/IO_SOUND/~RD: IC107.5 (~RD~); also elsewhere on the board
/IO_SOUND/~RESET: R901.1; also elsewhere on the board
/IO_SOUND/~WR: IC107.36 (~WR~); also elsewhere on the board
A8: IC107.9 (A0); also elsewhere on the board
A9: IC107.8 (A1); also elsewhere on the board
A11: U901.4; also elsewhere on the board
D0: IC107.34 (D0); also elsewhere on the board
D1: IC107.33 (D1); also elsewhere on the board
D2: IC107.32 (D2); also elsewhere on the board
D3: IC107.31 (D3); also elsewhere on the board
D4: IC107.30 (D4); also elsewhere on the board
D5: IC107.29 (D5); also elsewhere on the board
D6: IC107.28 (D6); also elsewhere on the board
D7: IC107.27 (D7); also elsewhere on the board
GND: IC107.7 (GND), LK1..6.2, LK1..6.4, LK1..6.6, LK1..6.8, LK1..6.10, LK1..6.12, Q101.3 (E), Q901.3 (E), U901.1, U901.2, U901.7 (GND), U901.9, U901.10, U901.12, U901.13; also elsewhere on the board
unnamed: IC107.6 (~CS~), U901.6
unnamed: IC107.35 (RESET), Q901.1 (C), R190.2
unnamed: Q101.2 (B), R113.2
unnamed: Q901.2 (B), R901.2
PA0: IC107.4 (PA0); also elsewhere on the board
PA1: IC107.3 (PA1); also elsewhere on the board
PA2: IC107.2 (PA2); also elsewhere on the board
PA3: IC107.1 (PA3); also elsewhere on the board
PA4: IC107.40 (PA4); also elsewhere on the board
PA5: IC107.39 (PA5); also elsewhere on the board
PA6: IC107.38 (PA6); also elsewhere on the board
PA7: IC107.37 (PA7); also elsewhere on the board
PC0: IC107.14 (PC0); also elsewhere on the board
PC1: IC107.15 (PC1); also elsewhere on the board
PC2: IC107.16 (PC2); also elsewhere on the board
PC3: IC107.17 (PC3); also elsewhere on the board

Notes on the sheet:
Note: substitute a BC337 for Q101.
<- (was printer port busy signal)


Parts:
C314, C318, C904: 0.1; C_Disc_D3.0mm_W2.0mm_P2.50mm
C315: 10V22; CP_Radial_D6.3mm_P2.50mm
C316: 16V100; CP_Radial_D6.3mm_P2.50mm
C317: 0.047; C_Disc_D3.0mm_W2.0mm_P2.50mm
D301, D302, D303: 1N4148; D_DO-35_SOD27_P7.62mm_Horizontal
IC301: LM358; DIP-8_W7.62mm_Socket
J1: Tape in; Jack_3.5mm_CUI_SJ1-3533NG_Horizontal
J2: Tape out; Jack_3.5mm_CUI_SJ1-3533NG_Horizontal
J3: Motor; CUI_MJ1_2503A
JP20: Jumper_2_Bridged; NetTie-2_SMD_Pad0.5mm
R307: 47k; R_Axial_DIN0207_L6.3mm_D2.5mm_P7.62mm_Horizontal
R309: 56R; R_Axial_DIN0207_L6.3mm_D2.5mm_P7.62mm_Horizontal
R310, R311: 18k; R_Axial_DIN0207_L6.3mm_D2.5mm_P7.62mm_Horizontal
R312: 100R; R_Axial_DIN0207_L6.3mm_D2.5mm_P7.62mm_Horizontal
R313, R314: 10k; R_Axial_DIN0207_L6.3mm_D2.5mm_P7.62mm_Horizontal
R315: 4k7; R_Axial_DIN0207_L6.3mm_D2.5mm_P7.62mm_Horizontal
R316: 1k; R_Axial_DIN0207_L6.3mm_D2.5mm_P7.62mm_Horizontal
R317: 470k; R_Axial_DIN0207_L6.3mm_D2.5mm_P7.62mm_Horizontal
RY30: G5Q-1A-DC5 (NO); Relay_SPST_Omron-G5Q-1A

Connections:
+5V: C316.1, D303.1 (K), R309.1, RY30.5; also elsewhere on the board
+5VA: C904.1, D301.1 (K), IC301.8 (V+), R309.2, R310.2, R311.2, R315.2
/IO_SOUND/CASRD: IC301.1, R307.2; also elsewhere on the board
/IO_SOUND/CASWR: C317.2, R315.1; also elsewhere on the board
/IO_SOUND/Tape/~MOTORINT: D303.2 (A), RY30.1; also elsewhere on the board
GND: JP20.1 (A); also elsewhere on the board
GNDA: C315.2, C316.2, C904.2, D302.2 (A), IC301.4 (V-), IC301.5 (+), J1.S, J2.S, JP20.2 (B), R313.1, R314.1, R316.2
unnamed: C314.1, D301.2 (A), D302.1 (K), IC301.3 (+), R310.1, R313.2
unnamed: C314.2, R312.1
unnamed: C315.1, IC301.2 (-), R307.1, R311.1, R314.2
unnamed: C317.1, R317.2
unnamed: C318.1, J3.T, RY30.3
unnamed: C318.2, J3.S, RY30.2
unnamed: IC301.6 (-), IC301.7
unnamed: J1.T, R312.2
unnamed: J2.T, R316.1, R317.1

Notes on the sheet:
3.5mm Sockets are CUI SJ1-3533NG
2.5mm audio jack, E.g. CUI MJ1-2503A


Board: 2 copper layers, 99.1 x 70.3 mm, 37 parts (1 on the bottom side), 57 nets.

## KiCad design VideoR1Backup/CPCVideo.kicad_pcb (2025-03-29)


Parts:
JP1: CPCM_VideoRAM_EdgeBottom; Edge36_2.54PS
JP2: CPCM_VideoRAM_EdgeTop; Edge36_2.54PS

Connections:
+5V: JP2.15 (Vcc); also elsewhere on the board
/RAM_GA/DISPEN: JP2.27 (DISPEN); also elsewhere on the board
/RAM_GA/HSYNC: JP2.26 (HSYNC); also elsewhere on the board
/RAM_GA/MA0_CCLK: JP1.21 (~MA0_CCLK); also elsewhere on the board
/RAM_GA/PHI: JP1.20 (CLK4); also elsewhere on the board
/RAM_GA/READY: JP2.20 (READY); also elsewhere on the board
/RAM_GA/VSYNC: JP2.25 (VSYNC); also elsewhere on the board
/RAM_GA/~244EN: JP1.23 (~244EN); also elsewhere on the board
/RAM_GA/~CAS: JP1.22 (~CAS); also elsewhere on the board
/RAM_GA/~CPU_ADDR: JP1.25 (~CPU_ADDR); also elsewhere on the board
/RAM_GA/~INT: JP2.19 (~INT); also elsewhere on the board
/RAM_GA/~IORQ: JP2.17 (~IORQ); also elsewhere on the board
/RAM_GA/~M1: JP2.16 (~M1); also elsewhere on the board
/RAM_GA/~MREQ: JP1.15 (~MREQ); also elsewhere on the board
/RAM_GA/~MWE: JP1.27 (~MWE); also elsewhere on the board
/RAM_GA/~RAMRD: JP1.18 (~RAMRD); also elsewhere on the board
/RAM_GA/~RAS: JP1.26 (~RAS); also elsewhere on the board
/RAM_GA/~RD: JP1.16 (~RD); also elsewhere on the board
/RAM_GA/~RESET: JP2.21 (~RSET); also elsewhere on the board
/RAM_GA/~ROMEN: JP1.17 (~ROMEN); also elsewhere on the board
A14: JP1.3 (A14); also elsewhere on the board
A15: JP2.3 (A15); also elsewhere on the board
GND: JP1.1 (GND), JP2.36 (GND); also elsewhere on the board
RD0: JP1.35 (RD0); also elsewhere on the board
RD1: JP2.35 (RD1); also elsewhere on the board
RD2: JP1.34 (RD2); also elsewhere on the board
RD3: JP2.34 (RD3); also elsewhere on the board
RD4: JP1.33 (RD4); also elsewhere on the board
RD5: JP2.33 (RD5); also elsewhere on the board
RD6: JP1.32 (RD6); also elsewhere on the board
RD7: JP2.32 (RD7); also elsewhere on the board


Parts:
C139, C140, C141: 220p; C_Disc_D3.0mm_W1.6mm_P2.50mm
J1: VIDEO OUT; 6PinDIN240Degree
Q102: 2SC1815Y; TO-92_HandSolder
Q103: 2N2369; TO-18-3
R125, R127, R129, R135: 680; R_Axial_DIN0207_L6.3mm_D2.5mm_P7.62mm_Horizontal
R126, R128, R130: 270; R_Axial_DIN0207_L6.3mm_D2.5mm_P7.62mm_Horizontal
R131: 3k3; R_Axial_DIN0207_L6.3mm_D2.5mm_P7.62mm_Horizontal
R132: 1k; R_Axial_DIN0207_L6.3mm_D2.5mm_P7.62mm_Horizontal
R133: 10k; R_Axial_DIN0207_L6.3mm_D2.5mm_P7.62mm_Horizontal
R134: 180; R_Axial_DIN0207_L6.3mm_D2.5mm_P7.62mm_Horizontal
R136: 150; R_Axial_DIN0207_L6.3mm_D2.5mm_P7.62mm_Horizontal
R137: 220; R_Axial_DIN0207_L6.3mm_D2.5mm_P7.62mm_Horizontal
R140: 100; R_Axial_DIN0207_L6.3mm_D2.5mm_P7.62mm_Horizontal
R141: 68; R_Axial_DIN0207_L6.3mm_D2.5mm_P7.62mm_Horizontal
X201: 16MHz CXO_DIP14; Oscillator_DIP-14

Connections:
+5V: Q102.2 (C), R125.2, R127.2, R129.2, R140.2; also elsewhere on the board
/RAM_GA/BLUE: C141.1, J1.3, R130.2
/RAM_GA/GREEN: C140.1, J1.2, R128.2
/RAM_GA/GateArrays/B: R129.1, R130.1, R133.2; also elsewhere on the board
/RAM_GA/GateArrays/G: R127.1, R128.1, R132.2; also elsewhere on the board
/RAM_GA/GateArrays/PHI: Q103.2 (B); also elsewhere on the board
/RAM_GA/GateArrays/R: R125.1, R126.1, R131.2; also elsewhere on the board
/RAM_GA/GateArrays/~SYNC: R135.1, R137.1; also elsewhere on the board
/RAM_GA/LUM: J1.6, R134.2, R136.1
/RAM_GA/PHI: R141.2; also elsewhere on the board
/RAM_GA/RED: C139.1, J1.1, R126.2
/RAM_GA/~SYNC: J1.4, R137.2
GND: C139.2, C140.2, C141.2, J1.5, J1.SH (Shield), Q103.1 (E), R136.2; also elsewhere on the board
unnamed: Q102.1 (E), R134.1
unnamed: Q102.3 (B), R131.1, R132.1, R133.1, R135.2
unnamed: Q103.3 (C), R140.1, R141.1

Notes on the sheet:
See Note 1
Note 1: RAM write timing. The original 4164 chips have separate pins for data in and data out. Modern SRAM use the same pins. This means that data being written to RAM needs to be rerouted through IC115 and the timings adjusted to suit. The existing ~244EN~ signal activates when the CPU is writing 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
I've switched oscillator circuit to a crystal oscillator to reduce component count, cost and space.
Original: ZTX312L Possible substitutes: BCX38, ZTX614 **Recommended: 2N2369 as used by Noel Llopis
6-pin DIN, 240 degrees. E.g. TE 5786676-1


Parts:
C104-1, C104-2: 0.1uF; C_Disc_D3.4mm_W2.1mm_P2.50mm
IC118: AMG40007; DIP-40_W15.24mm_Socket
IC918: AMG40010; DIP-40_W15.24mm_Socket
R138, R139: 12R 1/2W; R_Axial_DIN0309_L9.0mm_D3.2mm_P12.70mm_Horizontal

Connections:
+5V: C104-1.1, C104-2.1, IC118.22 (VCC1), IC118.38 (VCC1), IC918.6 (VDD1), IC918.25 (VDD2), R138.1, R139.1; also elsewhere on the board
/RAM_GA/DISPEN: IC118.23 (DISPEN), IC918.9 (DISPEN); also elsewhere on the board
/RAM_GA/GateArrays/B: IC118.32 (B), IC918.8 (B); also elsewhere on the board
/RAM_GA/GateArrays/G: IC118.34 (G), IC918.10 (G); also elsewhere on the board
/RAM_GA/GateArrays/PHI: IC118.39 (PHI), IC918.19 (PHI); also elsewhere on the board
/RAM_GA/GateArrays/R: IC118.36 (R), IC918.12 (R); also elsewhere on the board
/RAM_GA/GateArrays/XTAL: IC118.8 (XTAL), IC918.24 (CK16); also elsewhere on the board
/RAM_GA/GateArrays/~CAS_ADDR: IC118.6 (~CAS_ADDR), IC918.31 (~CASAD)
/RAM_GA/GateArrays/~SYNC: IC118.11 (~SYNC), IC918.5 (~SYNC); also elsewhere on the board
/RAM_GA/HSYNC: IC118.14 (HSYNC), IC918.11 (HSYNC); also elsewhere on the board
/RAM_GA/MA0_CCLK: IC118.40 (MA0_CCLK), IC918.4 (CCLK); also elsewhere on the board
/RAM_GA/READY: IC118.2 (READY), IC918.22 (READY); also elsewhere on the board
/RAM_GA/VSYNC: IC118.15 (VSYNC), IC918.13 (VSYNC); also elsewhere on the board
/RAM_GA/~244EN: IC118.4 (~244EN), IC918.23 (~244EN); also elsewhere on the board
/RAM_GA/~CAS: IC118.3 (~CAS), IC918.16 (~CAS); also elsewhere on the board
/RAM_GA/~CPU_ADDR: IC118.1 (~CPU_ADDR), IC918.14 (~CPU); also elsewhere on the board
/RAM_GA/~INT: IC118.10 (~INTERRUPT), IC918.32 (~INTERRUPT); also elsewhere on the board
/RAM_GA/~IORQ: IC118.16 (~IORQ), IC918.18 (~IORQ); also elsewhere on the board
/RAM_GA/~M1: IC118.17 (~M1), IC918.20 (~M1); also elsewhere on the board
/RAM_GA/~MREQ: IC118.18 (~MREQ), IC918.17 (~MREQ); also elsewhere on the board
/RAM_GA/~MWE: IC118.5 (~MWE), IC918.33 (~MWE); also elsewhere on the board
/RAM_GA/~RAMRD: IC118.13 (~RAMRD), IC918.29 (~RAMRD); also elsewhere on the board
/RAM_GA/~RAS: IC118.7 (~RAS), IC918.34 (~RAS); also elsewhere on the board
/RAM_GA/~RD: IC118.19 (~RD), IC918.21 (~RD); also elsewhere on the board
/RAM_GA/~RESET: IC118.37 (~RESET), IC918.7 (~RESET); also elsewhere on the board
/RAM_GA/~ROMEN: IC118.12 (~ROMEN), IC918.27 (~ROMEN); also elsewhere on the board
A14: IC118.21 (A14), IC918.30 (A14); also elsewhere on the board
A15: IC118.20 (A15), IC918.28 (A15); also elsewhere on the board
GND: C104-1.2, C104-2.2, IC118.35 (GND), IC918.15 (VSS1), IC918.26 (VSS2), IC918.36 (VSS3); also elsewhere on the board
unnamed: IC118.9 (VCC2), IC118.33 (VCC2), R138.2, R139.2
RD0: IC118.24 (D0), IC918.35 (D0); also elsewhere on the board
RD1: IC118.25 (D1), IC918.37 (D1); also elsewhere on the board
RD2: IC118.26 (D2), IC918.38 (D2); also elsewhere on the board
RD3: IC118.27 (D3), IC918.39 (D3); also elsewhere on the board
RD4: IC118.28 (D4), IC918.40 (D4); also elsewhere on the board
RD5: IC118.29 (D5), IC918.1 (D5); also elsewhere on the board
RD6: IC118.30 (D6), IC918.2 (D6); also elsewhere on the board
RD7: IC118.31 (D7), IC918.3 (D7); also elsewhere on the board

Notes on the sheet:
Close coupling to pin 35 (original note)
40007 or 40008. Requires a heatsink.
40010
Footprints for alternative gate arrays. Install one or other but NOT both.


Board: 2 copper layers, 99.1 x 70.3 mm, 30 parts (1 on the bottom side), 47 nets.

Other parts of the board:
X901: 16MHz CXO_DIP14; Oscillator_DIP-14

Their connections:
+5V: X901.14; also elsewhere on the board
/RAM_GA/GateArrays/XTAL: X901.8; also elsewhere on the board
GND: X901.7; also elsewhere on the board

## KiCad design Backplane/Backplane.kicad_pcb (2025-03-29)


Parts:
C1, C3: 220uF 100V; CP_Radial_D7.5mm_P2.50mm
C2: 470uF 6.3V; CP_Radial_D7.5mm_P2.50mm
C4: 0.1uF; C_Disc_D3.0mm_W2.0mm_P2.50mm
D1, D2: SA5.0CA-E3/54; D_DO-15_P12.70mm_Horizontal
D3: POWER; LED_D3.0mm
D4, D5, D6, D7, D8, D9, D10, D11, D12, D13, D14, D15, D16, D17, D18, D19, D20, D21, D22, D23, D24, D25, D26, D27, D28, D29, D30, D31, D32, D33, D34, D35, D36, D37, D38, D39, D40, D41, D42, D43, D44, D45, D46, D47, D48, D49, D50, D51: PESD5V0V1BA; D_SOD-323_HandSoldering
D53: SA12CA; D_DO-15_P12.70mm_Horizontal
F1: MF-R600-2; Fuse_Bourns_MF-RG600
H1, H2, H3, H4, H5, H6: MountingHole_Pad; MountingHole_3.2mm_M3
J1, J2, J3, J4: Conn_02x25_Odd_Even; PinSocket_2x25_P2.54mm_Vertical
J5, J6, J7, J8: Conn_02x36_Top_Bottom; Edge_Socket_2x36_2.54PS
J9, J10, J11: Conn_02x25_Top_Bottom; Edge_Socket_2x25_2.54PS
J12: Expansion Top (Edge connector); Edge25_2.54PS
J13: Expansion Bottom (Edge connector); Edge25_2.54PS
J14: USB_B; USB_B_OST_USB-B1HSxx_Horizontal
J15: TE 171826-4 ('Berg'); JST_EH_S4B-EH_1x04_P2.50mm_Horizontal
J16: Barrel_Jack_MountingPin; BarrelJack_Horizontal
J17: SCART POWER; PinHeader_1x02_P2.54mm_Horizontal
J18: TE 770997-1 ('Molex'); JST_EH_S4B-EH_1x04_P2.50mm_Horizontal
R1: 470; R_Axial_DIN0207_L6.3mm_D2.5mm_P7.62mm_Horizontal
SW1: SSP1S1M6xEA; E-Switch_SSP1_M6_A
SW2: PTS645VH58-2 LFS; SW_Tactile_SPST_Angled_PTS645Vx58-2LFS
TH1: B57238S0709M000; RV_Disc_D15.5mm_W5.9mm_P7.5mm
U1: RS6-0505S; Recom_RS6_Series_SIP8
U2: ADM708 or MAX708; DIP-8_W7.62mm_Socket
U3: TMU 3-0512; Converter_DCDC_muRata_CRE1xxxxxxSC_THT

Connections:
+5V: C2.1, C4.1, D2.1 (A1), D17.1 (A1), J1.27, J2.27, J3.27, J4.27, J5.15, J6.15, J7.15, J8.15, J9.17, J10.17, J11.17, J12.14, J15.1, J17.2, R1.1, U1.6 (Vout+), U2.2 (Vcc)
+12V: C3.1, D53.1 (A1), J15.4, U3.4 (+VOUT)
/A0: D35.1 (A1), J1.18, J2.18, J3.18, J4.18, J5.46, J6.46, J7.46, J8.46, J13.9
/A1: D12.1 (A1), J1.17, J2.17, J3.17, J4.17, J5.10, J6.10, J7.10, J8.10, J12.9
/A2: D34.1 (A1), J1.16, J2.16, J3.16, J4.16, J5.45, J6.45, J7.45, J8.45, J13.8
/A3: D11.1 (A1), J1.15, J2.15, J3.15, J4.15, J5.9, J6.9, J7.9, J8.9, J12.8
/A4: D33.1 (A1), J1.14, J2.14, J3.14, J4.14, J5.44, J6.44, J7.44, J8.44, J13.7
/A5: D10.1 (A1), J1.13, J2.13, J3.13, J4.13, J5.8, J6.8, J7.8, J8.8, J12.7
/A6: D32.1 (A1), J1.12, J2.12, J3.12, J4.12, J5.43, J6.43, J7.43, J8.43, J13.6
/A7: D9.1 (A1), J1.11, J2.11, J3.11, J4.11, J5.7, J6.7, J7.7, J8.7, J12.6
/A8: D31.1 (A1), J1.10, J2.10, J3.10, J4.10, J5.42, J6.42, J7.42, J8.42, J9.33, J10.33, J11.33, J13.5
/A9: D8.1 (A1), J1.9, J2.9, J3.9, J4.9, J5.6, J6.6, J7.6, J8.6, J9.8, J10.8, J11.8, J12.5
/A10: D30.1 (A1), J1.8, J2.8, J3.8, J4.8, J5.41, J6.41, J7.41, J8.41, J9.32, J10.32, J11.32, J13.4
/A11: D7.1 (A1), J1.7, J2.7, J3.7, J4.7, J5.5, J6.5, J7.5, J8.5, J9.7, J10.7, J11.7, J12.4
/A12: D29.1 (A1), J1.6, J2.6, J3.6, J4.6, J5.40, J6.40, J7.40, J8.40, J9.31, J10.31, J11.31, J13.3
/A13: D6.1 (A1), J1.5, J2.5, J3.5, J4.5, J5.4, J6.4, J7.4, J8.4, J9.6, J10.6, J11.6, J12.3
/A14: D28.1 (A1), J1.4, J2.4, J3.4, J4.4, J5.39, J6.39, J7.39, J8.39, J9.30, J10.30, J11.30, J13.2
/A14OUT: J5.38, J6.38, J7.38, J8.38
/A15: D5.1 (A1), J1.3, J2.3, J3.3, J4.3, J5.3, J6.3, J7.3, J8.3, J9.5, J10.5, J11.5, J12.2
/A15OUT: J5.2, J6.2, J7.2, J8.2
/BC1: J9.44, J10.44, J11.44
/BDIR: J9.43, J10.43, J11.43
/CASRD: J9.2, J10.2, J11.2
/CASWR: J9.27, J10.27, J11.27
/CLK4: D51.1 (A1), J1.50, J2.50, J3.50, J4.50, J5.56, J6.56, J7.56, J8.56, J13.25
/CURSOR: D49.1 (A1), J1.46, J2.46, J3.46, J4.46, J5.55, J6.55, J7.55, J8.55, J13.23
/D0: D39.1 (A1), J1.26, J2.26, J3.26, J4.26, J5.50, J6.50, J7.50, J8.50, J9.41, J10.41, J11.41, J13.13
/D1: D16.1 (A1), J1.25, J2.25, J3.25, J4.25, J5.14, J6.14, J7.14, J8.14, J9.16, J10.16, J11.16, J12.13
/D2: D38.1 (A1), J1.24, J2.24, J3.24, J4.24, J5.49, J6.49, J7.49, J8.49, J9.40, J10.40, J11.40, J13.12
/D3: D15.1 (A1), J1.23, J2.23, J3.23, J4.23, J5.13, J6.13, J7.13, J8.13, J9.15, J10.15, J11.15, J12.12
/D4: D37.1 (A1), J1.22, J2.22, J3.22, J4.22, J5.48, J6.48, J7.48, J8.48, J9.39, J10.39, J11.39, J13.11
/D5: D14.1 (A1), J1.21, J2.21, J3.21, J4.21, J5.12, J6.12, J7.12, J8.12, J9.14, J10.14, J11.14, J12.11
/D6: D36.1 (A1), J1.20, J2.20, J3.20, J4.20, J5.47, J6.47, J7.47, J8.47, J9.38, J10.38, J11.38, J13.10
/D7: D13.1 (A1), J1.19, J2.19, J3.19, J4.19, J5.11, J6.11, J7.11, J8.11, J9.13, J10.13, J11.13, J12.10
/DISPEN: J5.27, J6.27, J7.27, J8.27
/HSYNC: J5.26, J6.26, J7.26, J8.26
/LEFT: J9.3, J10.3, J11.3
/LPEN: D27.1 (A1), J1.47, J2.47, J3.47, J4.47, J5.24, J6.24, J7.24, J8.24, J12.24
/MOTOR: J9.45, J10.45, J11.45
/PA0: J9.34, J10.34, J11.34
/PA1: J9.9, J10.9, J11.9
/PA2: J9.35, J10.35, J11.35
/PA3: J9.10, J10.10, J11.10
/PA4: J9.36, J10.36, J11.36
/PA5: J9.11, J10.11, J11.11
/PA6: J9.37, J10.37, J11.37
/PA7: J9.12, J10.12, J11.12
/PC0: J9.46, J10.46, J11.46
/PC1: J9.22, J10.22, J11.22
/PC2: J9.47, J10.47, J11.47
/PC3: J9.23, J10.23, J11.23
/PLUS: J14.3 (D+)
/PRTBSY: J9.49, J10.49, J11.49
/RAMA16: J5.66, J6.66, J7.66, J8.66
/RAMA17: J5.30, J6.30, J7.30, J8.30
/RAMA18: J5.65, J6.65, J7.65, J8.65
/RAMDIS: D26.1 (A1), J1.45, J2.45, J3.45, J4.45, J5.23, J6.23, J7.23, J8.23, J12.23
/RD0: J5.71, J6.71, J7.71, J8.71
/RD1: J5.35, J6.35, J7.35, J8.35
/RD2: J5.70, J6.70, J7.70, J8.70
/RD3: J5.34, J6.34, J7.34, J8.34
/RD4: J5.69, J6.69, J7.69, J8.69
/RD5: J5.33, J6.33, J7.33, J8.33
/RD6: J5.68, J6.68, J7.68, J8.68
/RD7: J5.32, J6.32, J7.32, J8.32
/READY: D23.1 (A1), J1.39, J2.39, J3.39, J4.39, J5.20, J6.20, J7.20, J8.20, J12.20
/RIGHT: J9.28, J10.28, J11.28
/ROMDIS: D25.1 (A1), J1.43, J2.43, J3.43, J4.43, J12.22
/SOUND: D4.1 (A1), J1.1, J2.1, J3.1, J4.1, J9.1, J10.1, J11.1, J12.1
/SPARE1: J5.1, J6.1, J7.1, J8.1
/SPARE2: J5.22, J6.22, J7.22, J8.22
/SPARE3: J5.31, J6.31, J7.31, J8.31
/SPARE4: J5.67, J6.67, J7.67, J8.67
/SPARE5: J5.72, J6.72, J7.72, J8.72
/SWITCHED_5V: C1.1, SW1.1 (A), U1.2 (Vin+), U2.4 (PFI), U3.2 (+VIN)
/UGND: C1.2, D1.2 (A2), J14.4 (GND), J14.5 (Shield), U1.1 (Vin-)
/VBUS: F1.2, J14.1 (VBUS)
/VSYNC: J5.25, J6.25, J7.25, J8.25, J9.24, J10.24, J11.24
/~244EN: J5.59, J6.59, J7.59, J8.59
/~BRST: D46.1 (A1), J1.40, J2.40, J3.40, J4.40, J13.20, SW2.1, U2.1 (~MR)
/~BUSAK: D45.1 (A1), J1.38, J2.38, J3.38, J4.38, J13.19
/~BUSRQ: D22.1 (A1), J1.37, J2.37, J3.37, J4.37, J12.19
/~CAS: J5.58, J6.58, J7.58, J8.58
/~CPU_ADDR: J5.61, J6.61, J7.61, J8.61, J9.48, J10.48, J11.48
/~EXP: D50.1 (A1), J1.48, J2.48, J3.48, J4.48, J9.50, J10.50, J11.50, J13.24
/~HALT: D43.1 (A1), J1.34, J2.34, J3.34, J4.34, J13.17
/~INT: D21.1 (A1), J1.35, J2.35, J3.35, J4.35, J5.19, J6.19, J7.19, J8.19, J12.18
/~IORQ: D19.1 (A1), J1.31, J2.31, J3.31, J4.31, J5.17, J6.17, J7.17, J8.17, J9.19, J10.19, J11.19, J12.16
/~M1: D18.1 (A1), J1.29, J2.29, J3.29, J4.29, J5.16, J6.16, J7.16, J8.16, J9.18, J10.18, J11.18, J12.15
/~MA0_CCLK: J5.57, J6.57, J7.57, J8.57
/~MREQ: D40.1 (A1), J1.28, J2.28, J3.28, J4.28, J5.51, J6.51, J7.51, J8.51, J13.14
/~MWE: J5.63, J6.63, J7.63, J8.63
/~NMI: D44.1 (A1), J1.36, J2.36, J3.36, J4.36, J13.18
/~RAMCS: J5.64, J6.64, J7.64, J8.64
/~RAMOE: J5.28, J6.28, J7.28, J8.28
/~RAMRD: D48.1 (A1), J1.44, J2.44, J3.44, J4.44, J5.54, J6.54, J7.54, J8.54, J13.22
/~RAMWE: J5.29, J6.29, J7.29, J8.29
/~RAS: J5.62, J6.62, J7.62, J8.62
/~RD: D42.1 (A1), J1.32, J2.32, J3.32, J4.32, J5.52, J6.52, J7.52, J8.52, J9.42, J10.42, J11.42, J13.16
/~RFSH: D41.1 (A1), J1.30, J2.30, J3.30, J4.30, J13.15
/~ROMEN: D47.1 (A1), J1.42, J2.42, J3.42, J4.42, J5.53, J6.53, J7.53, J8.53, J13.21
/~RSET: D24.1 (A1), J1.41, J2.41, J3.41, J4.41, J5.21, J6.21, J7.21, J8.21, J9.21, J10.21, J11.21, J12.21, U2.7 (~RESET)
/~WR: D20.1 (A1), J1.33, J2.33, J3.33, J4.33, J5.18, J6.18, J7.18, J8.18, J9.20, J10.20, J11.20, J12.17
/~XCPU_AD: J5.60, J6.60, J7.60, J8.60
GND: C2.2, C3.2, C4.2, D2.2 (A2), D3.1 (K), D4.2 (A2), D5.2 (A2), D6.2 (A2), D7.2 (A2), D8.2 (A2), D9.2 (A2), D10.2 (A2), D11.2 (A2), D12.2 (A2), D13.2 (A2), D14.2 (A2), D15.2 (A2), D16.2 (A2), D17.2 (A2), D18.2 (A2), D19.2 (A2), D20.2 (A2), D21.2 (A2), D22.2 (A2), D23.2 (A2), D24.2 (A2), D25.2 (A2), D26.2 (A2), D27.2 (A2), D28.2 (A2), D29.2 (A2), D30.2 (A2), D31.2 (A2), D32.2 (A2), D33.2 (A2), D34.2 (A2), D35.2 (A2), D36.2 (A2), D37.2 (A2), D38.2 (A2), D39.2 (A2), D40.2 (A2), D41.2 (A2), D42.2 (A2), D43.2 (A2), D44.2 (A2), D45.2 (A2), D46.2 (A2), D47.2 (A2), D48.2 (A2), D49.2 (A2), D50.2 (A2), D51.2 (A2), D53.2 (A2), H1.1, H2.1, H3.1, H4.1, H5.1, H6.1, J1.2, J1.49, J2.2, J2.49, J3.2, J3.49, J4.2, J4.49, J5.36, J5.37, J6.36, J6.37, J7.36, J7.37, J8.36, J8.37, J9.4, J9.25, J9.26, J9.29, J10.4, J10.25, J10.26, J10.29, J11.4, J11.25, J11.26, J11.29, J12.25, J13.1, J15.2, J15.3, J17.1, SW2.2, U1.7 (Vout-), U2.3 (GND), U3.1 (-VIN), U3.3 (-VOUT)
unnamed: D1.1 (A1), F1.1, TH1.2
unnamed: D3.2 (A), R1.2
unnamed: SW1.2 (B), TH1.1

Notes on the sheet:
MX4 (not validated) 4(no) slots + edge connector
Video-RAM (not validated) 3(no) slots
IO-Sound (not validated) 3(no) slots
POWER IN
RESET
DISC POWER OUT
ESD PROTECTION FOR EXPANSION CONNECTOR
Expansion (Edge connector)
SCART POWER AND JACK STORAGE
Attach a lead and 2.1mm phono plug to the power out. Can be used to power a CPC to SCART lead. Socket can be used for safe storage of the plug. Plug should be wired centre-positive.


Board: 2 copper layers, 246.4 x 120.7 mm, 88 parts (1 on the bottom side), 107 nets.

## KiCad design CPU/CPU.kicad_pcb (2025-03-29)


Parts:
C901, C902, C903: 100n; C_Rect_L4.6mm_W2.0mm_P2.50mm_MKS02_FKP02
C904: 10uF; CP_Radial_D5.0mm_P2.00mm
D901, D902, D903, D904, D905, D906, D907, D908, D909, D910, D911, D912, D913, D914, D915, D916: LED; LED_D3.0mm
IC111: Z80CPU; DIP-40_W15.24mm_Socket
IC901, IC902: 74LS245; DIP-20_W7.62mm_Socket
J1: MX4 Connector; IDC-Header_2x25_P2.54mm_Horizontal
R109, R110: 2k2; R_Axial_DIN0207_L6.3mm_D2.5mm_P7.62mm_Horizontal
RN901, RN902: 470; R_Array_SIP9

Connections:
+5V: C901.1, C902.1, C903.1, C904.1, IC111.11 (VCC), IC901.1 (A->B), IC901.20 (VCC), IC902.1 (A->B), IC902.20 (VCC), J1.24, R109.2, R110.2, RN901.1 (common), RN902.1 (common)
/CLK4: IC111.6 (~CLK~), J1.1
/READY: IC111.24 (~WAIT~), J1.12
/~BUSAK: IC111.23 (~BUSACK~), J1.13
/~BUSRQ: IC111.25 (~BUSRQ~), J1.14, R110.1
/~HALT: IC111.18 (~HALT~), J1.17
/~INT: IC111.16 (~INT~), J1.16
/~IORQ: IC111.20 (~IORQ~), IC901.19 (CE), IC902.19 (CE), J1.20
/~M1: IC111.27 (~M1~), J1.22
/~MREQ: IC111.19 (~MREQ~), J1.23
/~NMI: IC111.17 (~NMI~), J1.15, R109.1
/~RD: IC111.21 (~RD~), J1.19
/~RESET: IC111.26 (~RESET~), J1.10
/~RFSH: IC111.28 (~RFSH~), J1.21
/~WR: IC111.22 (~WR~), J1.18
A0: IC111.30 (A0), IC902.9 (A7), J1.33
A1: IC111.31 (A1), IC902.8 (A6), J1.34
A2: IC111.32 (A2), IC902.7 (A5), J1.35
A3: IC111.33 (A3), IC902.6 (A4), J1.36
A4: IC111.34 (A4), IC902.5 (A3), J1.37
A5: IC111.35 (A5), IC902.4 (A2), J1.38
A6: IC111.36 (A6), IC902.3 (A1), J1.39
A7: IC111.37 (A7), IC902.2 (A0), J1.40
A8: IC111.38 (A8), IC901.9 (A7), J1.41
A9: IC111.39 (A9), IC901.8 (A6), J1.42
A10: IC111.40 (A10), IC901.7 (A5), J1.43
A11: IC111.1 (A11), IC901.6 (A4), J1.44
A12: IC111.2 (A12), IC901.5 (A3), J1.45
A13: IC111.3 (A13), IC901.4 (A2), J1.46
A14: IC111.4 (A14), IC901.3 (A1), J1.47
A15: IC111.5 (A15), IC901.2 (A0), J1.48
D0: IC111.14 (D0), J1.25
D1: IC111.15 (D1), J1.26
D2: IC111.12 (D2), J1.27
D3: IC111.8 (D3), J1.28
D4: IC111.7 (D4), J1.29
D5: IC111.9 (D5), J1.30
D6: IC111.10 (D6), J1.31
D7: IC111.13 (D7), J1.32
GND: C901.2, C902.2, C903.2, C904.2, IC111.29 (GND), IC901.10 (GND), IC902.10 (GND), J1.2, J1.49
unnamed: D901.1 (K), IC901.18 (B0)
unnamed: D901.2 (A), RN901.2 (R1)
unnamed: D902.1 (K), IC901.17 (B1)
unnamed: D902.2 (A), RN901.3 (R2)
unnamed: D903.1 (K), IC901.16 (B2)
unnamed: D903.2 (A), RN901.4 (R3)
unnamed: D904.1 (K), IC901.15 (B3)
unnamed: D904.2 (A), RN901.5 (R4)
unnamed: D905.1 (K), IC901.14 (B4)
unnamed: D905.2 (A), RN901.6 (R5)
unnamed: D906.1 (K), IC901.13 (B5)
unnamed: D906.2 (A), RN901.7 (R6)
unnamed: D907.1 (K), IC901.12 (B6)
unnamed: D907.2 (A), RN901.8 (R7)
unnamed: D908.1 (K), IC901.11 (B7)
unnamed: D908.2 (A), RN901.9 (R8)
unnamed: D909.1 (K), IC902.18 (B0)
unnamed: D909.2 (A), RN902.2 (R1)
unnamed: D910.1 (K), IC902.17 (B1)
unnamed: D910.2 (A), RN902.3 (R2)
unnamed: D911.1 (K), IC902.16 (B2)
unnamed: D911.2 (A), RN902.4 (R3)
unnamed: D912.1 (K), IC902.15 (B3)
unnamed: D912.2 (A), RN902.5 (R4)
unnamed: D913.1 (K), IC902.14 (B4)
unnamed: D913.2 (A), RN902.6 (R5)
unnamed: D914.1 (K), IC902.13 (B5)
unnamed: D914.2 (A), RN902.7 (R6)
unnamed: D915.1 (K), IC902.12 (B6)
unnamed: D915.2 (A), RN902.8 (R7)
unnamed: D916.1 (K), IC902.11 (B7)
unnamed: D916.2 (A), RN902.9 (R8)


Board: 2 copper layers, 99.1 x 65.9 mm, 28 parts (0 on the bottom side), 72 nets.

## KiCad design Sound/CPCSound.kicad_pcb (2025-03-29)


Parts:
C1, C2: 0.1nF; C_Disc_D3.0mm_W2.0mm_P2.50mm
JP1: CPCM_IOSound_EdgeBottom; Edge25_2.54PS
JP2: CPCM_IOSound_EdgeTop; Edge25_2.54PS

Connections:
+5V: C1.1, C2.1, JP2.17 (Vcc); also elsewhere on the board
/IO_SOUND/ALEFT: JP2.3 (LEFT); also elsewhere on the board
/IO_SOUND/ARIGHT: JP1.3 (RIGHT); also elsewhere on the board
/IO_SOUND/BC1: JP1.19 (BC1); also elsewhere on the board
/IO_SOUND/BDIR: JP1.18 (BDIR); also elsewhere on the board
/IO_SOUND/SOUND: JP2.1 (SOUND); also elsewhere on the board
/IO_SOUND/SOUND_CLK: JP1.23 (~CPU_ADDR); also elsewhere on the board
/IO_SOUND/~RESET: JP2.21 (~RSET); also elsewhere on the board
GND: C1.2, C2.2, JP1.1 (GND), JP2.25 (GND); also elsewhere on the board
PA0: JP1.9 (PA0); also elsewhere on the board
PA1: JP2.9 (PA1); also elsewhere on the board
PA2: JP1.10 (PA2); also elsewhere on the board
PA3: JP2.10 (PA3); also elsewhere on the board
PA4: JP1.11 (PA4); also elsewhere on the board
PA5: JP2.11 (PA5); also elsewhere on the board
PA6: JP1.12 (PA6); also elsewhere on the board
PA7: JP2.12 (PA7); also elsewhere on the board
PC0: JP1.21 (PC0); also elsewhere on the board
PC1: JP2.22 (PC1); also elsewhere on the board
PC2: JP1.22 (PC2); also elsewhere on the board
PC3: JP2.23 (PC3); also elsewhere on the board

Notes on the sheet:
TODO: Check DB-9 footprint - are the holes too small?? DONE Check the stereo out jack orientation (left vs right)


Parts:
D191, D192, D193, D194, D195, D196, D197, D198, D199, D200, D201, D202, D203, D204, D205, D206, D207, D208, D209, D210, D211, D212, D213, D214, D215, D216, D217, D218, D219, D220, D221, D222, D223, D224, D225, D226, D227: PESD5V0V1BA; D_SOD-323_HandSoldering
IC101: 74LS145; DIP-16_W7.62mm_Socket
IC102: AY-3-8910; DIP-40_W15.24mm_Socket
J102: Paddle Port (9-Pin D); DSUB-9_Male_Horizontal_P2.77x2.84mm_EdgePinOffset9.90mm_Hou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
J103: AudioJack3_SwitchTR; Jack_3.5mm_CUI_SJ1-3535NG_Horizontal
J192: Paddle Port 2 (9-Pin D); DSUB-9_Male_Horizontal_P2.77x2.84mm_EdgePinOffset9.90mm_Hou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
J193: Conn_01x10_Male; PinHeader_2x05_P2.54mm_Vertical
JP3: Conn_02x10_Odd_Even; IDC-Header_2x10_P2.54mm_Vertical
NT1: Net-Tie_2; NetTie-2_SMD_Pad0.5mm
R114, R115, R116, R117, R120: 10k; R_Axial_DIN0207_L6.3mm_D2.5mm_P7.62mm_Horizontal
R118, R119: 22k; R_Axial_DIN0207_L6.3mm_D2.5mm_P7.62mm_Horizontal
R121, R122, R123: 1k; R_Axial_DIN0207_L6.3mm_D2.5mm_P7.62mm_Horizontal
RN901: 2k2; R_Array_SIP9

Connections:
+5V: IC101.16 (VCC), IC102.25 (A8), IC102.28 (BC2), IC102.40 (Vcc), RN901.1 (common); also elsewhere on the board
/IO_SOUND/A: IC102.4 (ANALOG_A), R116.1, R120.2, R123.2
/IO_SOUND/ALEFT: J103.TN; also elsewhere on the board
/IO_SOUND/ARIGHT: J103.RN; also elsewhere on the board
/IO_SOUND/AYA0: D201.1 (A1), D209.1 (A1), IC102.21 (IOA0), J102.1, J192.1, JP3.4, RN901.2 (R1)
/IO_SOUND/AYA1: D202.1 (A1), D210.1 (A1), IC102.20 (IOA1), J102.2, J192.2, JP3.6, RN901.3 (R2)
/IO_SOUND/AYA2: D203.1 (A1), D213.1 (A1), IC102.19 (IOA2), J102.3, J192.3, JP3.8, RN901.4 (R3)
/IO_SOUND/AYA3: D204.1 (A1), D212.1 (A1), IC102.18 (IOA3), J102.4, J192.4, JP3.10, RN901.5 (R4)
/IO_SOUND/AYA4: D205.1 (A1), D215.1 (A1), IC102.17 (IOA4), J102.6, J192.5, JP3.12, RN901.6 (R5)
/IO_SOUND/AYA5: D206.1 (A1), D214.1 (A1), IC102.16 (IOA5), J102.7, J192.6, JP3.14, RN901.7 (R6)
/IO_SOUND/AYA6: D207.1 (A1), D211.1 (A1), IC102.15 (IOA6), J102.5, J192.7, JP3.16, RN901.8 (R7)
/IO_SOUND/AYA7: D208.1 (A1), IC102.14 (IOA7), JP3.18, RN901.9 (R8)
/IO_SOUND/AYB0: D220.1 (A1), IC102.13 (IOB0), J193.10
/IO_SOUND/AYB1: D221.1 (A1), IC102.12 (IOB1), J193.9
/IO_SOUND/AYB2: D222.1 (A1), IC102.11 (IOB2), J193.8
/IO_SOUND/AYB3: D223.1 (A1), IC102.10 (IOB3), J193.7
/IO_SOUND/AYB4: D224.1 (A1), IC102.9 (IOB4), J193.6
/IO_SOUND/AYB5: D225.1 (A1), IC102.8 (IOB5), J193.5
/IO_SOUND/AYB6: D226.1 (A1), IC102.7 (IOB6), J193.4
/IO_SOUND/AYB7: D227.1 (A1), IC102.6 (IOB7), J193.3
/IO_SOUND/B: IC102.3 (ANALOG_B), R115.1, R118.2, R119.2, R122.2
/IO_SOUND/BC1: IC102.29 (BC1); also elsewhere on the board
/IO_SOUND/BDIR: IC102.27 (BDIR); also elsewhere on the board
/IO_SOUND/C: IC102.38 (ANALOG_C), R114.1, R117.2, R121.2
/IO_SOUND/COMMON: D200.1 (A1), D217.1 (A1), IC101.11 (Q9), J102.8, JP3.1
/IO_SOUND/COM_2: D197.1 (A1), D216.1 (A1), IC101.7 (Q6), J102.9, J192.8, JP3.7
/IO_SOUND/SLEFT: D218.1 (A1), J103.T, R119.1, R120.1
/IO_SOUND/SOUND: R114.2, R115.2, R116.2; also elsewhere on the board
/IO_SOUND/SOUND_CLK: IC102.22 (CLOCK); also elsewhere on the board
/IO_SOUND/SRIGHT: D219.1 (A1), J103.R, R117.1, R118.1
/IO_SOUND/Y1: D191.1 (A1), IC101.1 (Q0), JP3.19
/IO_SOUND/Y2: D192.1 (A1), IC101.2 (Q1), JP3.17
/IO_SOUND/Y3: D193.1 (A1), IC101.3 (Q2), JP3.15
/IO_SOUND/Y4: D194.1 (A1), IC101.4 (Q3), JP3.13
/IO_SOUND/Y5: D195.1 (A1), IC101.5 (Q4), JP3.11
/IO_SOUND/Y6: D196.1 (A1), IC101.6 (Q5), JP3.9
/IO_SOUND/Y8: D198.1 (A1), IC101.9 (Q7), JP3.5
/IO_SOUND/Y9: D199.1 (A1), IC101.10 (Q8), JP3.3
/IO_SOUND/~RESET: IC102.23 (~RESET); also elsewhere on the board
GND: D191.2 (A2), D192.2 (A2), D193.2 (A2), D194.2 (A2), D195.2 (A2), D196.2 (A2), D197.2 (A2), D198.2 (A2), D199.2 (A2), D200.2 (A2), D201.2 (A2), D202.2 (A2), D203.2 (A2), D204.2 (A2), D205.2 (A2), D206.2 (A2), D207.2 (A2), D208.2 (A2), D209.2 (A2), D210.2 (A2), D211.2 (A2), D212.2 (A2), D213.2 (A2), D214.2 (A2), D215.2 (A2), D216.2 (A2), D217.2 (A2), D220.2 (A2), D221.2 (A2), D222.2 (A2), D223.2 (A2), D224.2 (A2), D225.2 (A2), D226.2 (A2), D227.2 (A2), IC101.8 (GND), IC102.1 (Vss), IC102.24 (~A9), J193.1, J193.2, NT1.1; also elsewhere on the board
GNDA: D218.2 (A2), D219.2 (A2), J103.S, NT1.2, R121.1, R122.1, R123.1
PA0: IC102.37 (DA0); also elsewhere on the board
PA1: IC102.36 (DA1); also elsewhere on the board
PA2: IC102.35 (DA2); also elsewhere on the board
PA3: IC102.34 (DA3); also elsewhere on the board
PA4: IC102.33 (DA4); also elsewhere on the board
PA5: IC102.32 (DA5); also elsewhere on the board
PA6: IC102.31 (DA6); also elsewhere on the board
PA7: IC102.30 (DA7); also elsewhere on the board
PC0: IC101.15 (P0); also elsewhere on the board
PC1: IC101.14 (P1); also elsewhere on the board
PC2: IC101.13 (P2); also elsewhere on the board
PC3: IC101.12 (P3); also elsewhere on the board

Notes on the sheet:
Modifications --- Replaced the AY-3-8912 with a '8910 (because they're cheaper). The extra port B has been brought out to header pins in case you want to use it (see below). A second joystick port has been added. Sound outputs to the bus as both separate left and right signals and stereo mix. This 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
Socket is CUI SJ1-3535NG
6128 left hand connector
6128 right hand connector
Optional pull-ups. Only for AY variants which don't have them internally.
(Original CPC464 keyboard connector)
NOTE: Connector rows (left/right) are flipped on the PCB to make cabling compatible with the CPC Modular keyboard.
TVS diodes (SMT)


Board: 2 copper layers, 99.1 x 71.1 mm, 60 parts (1 on the bottom side), 53 nets.

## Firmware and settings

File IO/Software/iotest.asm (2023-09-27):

org $0000

STARTUP_entry_point:              ;{{Addr=$0591 Code Calls/jump count: 1 Data use count: 0}}
        di                        ;{{0591:f3}} 
        ld      bc,$f782          ;{{0592:0182f7}} 
        out     (c),c             ;{{0595:ed49}} 

        ld      bc,$f400          ;{{0597:0100f4}} ; initialise PPI port A data
        out     (c),c             ;{{059a:ed49}} 

        ld      bc,$f600          ;{{059c:0100f6}} ; initialise PPI port C data 
                                  ;; - select keyboard line 0
                                  ;; - PSG control inactive
                                  ;; - cassette motor off
                                  ;; - cassette write data "0"
        out     (c),c             ;{{059f:ed49}} ; set PPI port C data

loop:
        inc c
		out (c),c
		jr loop
		
		
		
		

        ld      bc,$ef7f          ;{{05a1:017fef}} 
        out     (c),c             ;{{05a4:ed49}} 

        ld      b,$f5             ;{{05a6:06f5}} ; PPI port B inputs
        in      a,(c)             ;{{05a8:ed78}} Bits 4..1 are factory set links for (sales) region
        and     $10               ;{{05aa:e610}} bit4 = 50/60Hz config (60Hz if installed)
		
		call CAS_START_MOTOR
		call CAS_STOP_MOTOR
		
		halt
		
		
;;=====================================================================
;; CAS START MOTOR
;;
;; start cassette motor (if cassette motor was previously off
;; allow to to achieve full rotational speed)
CAS_START_MOTOR:                  ;{{Addr=$2bbb Code Calls/jump count: 2 Data use count: 1}}
        ld      a,$10             ;{{2bbb:3e10}}  start cassette motor
        jr      CAS_RESTORE_MOTOR ;{{2bbd:1802}}  CAS RESTORE MOTOR 

;;=====================================================================
;; CAS STOP MOTOR

CAS_STOP_MOTOR:                   ;{{Addr=$2bbf Code Calls/jump count: 2 Data use count: 1}}
        ld      a,$ef             ;{{2bbf:3eef}}  stop cassette motor

;;=====================================================================
;; CAS RESTORE MOTOR
;;
;; - if motor was switched from off->on, delay for a time to allow
;; cassette motor to achieve full rotational speed
;; - if motor was switched from on->off, do nothing

;; bit 4 of register A = cassette motor state
CAS_RESTORE_MOTOR:                ;{{Addr=$2bc1 Code Calls/jump count: 2 Data use count: 1}}
        push    bc                ;{{2bc1:c5}} 

        ld      b,$f6             ;{{2bc2:06f6}}  B = I/O address for PPI port C 
        in      c,(c)             ;{{2bc4:ed48}}  read current inputs (includes cassette input data)
        inc     b                 ;{{2bc6:04}}  B = I/O address for PPI control		

        and     $10               ;{{2bc7:e610}}  isolate cassette motor state from requested
                                  ; cassette motor status
									
        ld      a,$08             ;{{2bc9:3e08}}  %00001000	= cassette motor off
        jr      z,_cas_restore_motor_8;{{2bcb:2801}} 

        inc     a                 ;{{2bcd:3c}}  %00001001 = cassette motor on

_cas_restore_motor_8:             ;{{Addr=$2bce Code Calls/jump count: 1 Data use count: 0}}
        out     (c),a             ;{{2bce:ed79}}  set the requested motor state
                                  ; (uses PPI Control bit set/reset feature)

        scf                       ;{{2bd0:37}} 
        jr      z,_cas_restore_motor_18;{{2bd1:280c}} 

        ld      a,c               ;{{2bd3:79}} 
        and     $10               ;{{2bd4:e610}}  previous state

        push    bc                ;{{2bd6:c5}} 
        ld      bc,$00c8          ;{{2bd7:01c800}}  delay in 1/100ths of a second ##LIT##;WARNING: Code area used as literal
        scf                       ;{{2bda:37}} 
        call    z,delay__check_for_escape;{{2bdb:cce22b}}  delay for 2 seconds
        pop     bc                ;{{2bde:c1}} 

_cas_restore_motor_18:            ;{{Addr=$2bdf Code Calls/jump count: 1 Data use count: 0}}
        ld      a,c               ;{{2bdf:79}} 
        pop     bc                ;{{2be0:c1}} 
        ret                       ;{{2be1:c9}} 

;;=================================================================
;; delay & check for escape
;; allows cassette motor to achieve full rotational speed

;; entry conditions:
;; B = delay factor in 1/100ths of a second

;; exit conditions:
;; c = delay completed and escape was not pressed
;; nc = escape was pressed

delay__check_for_escape:          ;{{Addr=$2be2 Code Calls/jump count: 3 Data use count: 0}}
        push    bc                ;{{2be2:c5}} 
        push    hl                ;{{2be3:e5}} 
        call    tenth_of_a_second_delay;{{2be4:cdf92b}} ; 1/100th of a second delay

        ld      a,$42             ;{{2be7:3e42}} ; keycode for escape key 
;        call    KM_TEST_KEY       ;{{2be9:cd451e}} ; check for escape pressed (km test key)
                                  ;; if non-zero then escape key has been pressed
                                  ;; if zero, then escape key is not pressed
        pop     hl                ;{{2bec:e1}} 
        pop     bc                ;{{2bed:c1}} 
;        jr      nz,_delay__check_for_escape_14;{{2bee:2007}} ; escape key pressed?

;; continue delay
        dec     bc                ;{{2bf0:0b}} 
        ld      a,b               ;{{2bf1:78}} 
        or      c                 ;{{2bf2:b1}} 
        jr      nz,delay__check_for_escape;{{2bf3:20ed}} 

;; delay completed successfully and escape was not pressed
        scf                       ;{{2bf5:37}} 
        ret                       ;{{2bf6:c9}} 

;; escape was pressed
_delay__check_for_escape_14:      ;{{Addr=$2bf7 Code Calls/jump count: 1 Data use count: 0}}
        xor     a                 ;{{2bf7:af}} 
        ret                       ;{{2bf8:c9}} 

;;========================================================================================
;; tenth of a second delay

tenth_of_a_second_delay:          ;{{Addr=$2bf9 Code Calls/jump count: 2 Data use count: 0}}
        ld      bc,$0682          ;{{2bf9:018206}}  [3] ##LIT##;WARNING: Code area used as literal

;; total delay is ((BC-1)*(2+1+1+3)) + (2+1+1+2) + 3 + 3 = 11667 microseconds
;; there are 1000000 microseconds in a second
;; therefore delay is 11667/1000000 = 0.01 seconds or 1/100th of a second

_tenth_of_a_second_delay_1:       ;{{Addr=$2bfc Code Calls/jump count: 1 Data use count: 0}}
        dec     bc                ;{{2bfc:0b}}  [2]
        ld      a,b               ;{{2bfd:78}}  [1]
        or      c                 ;{{2bfe:b1}}  [1]
        jr      nz,_tenth_of_a_second_delay_1;{{2bff:20fb}}  [3]

        ret                       ;{{2c01:c9}}  [3]

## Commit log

2023-09-29 Added image to readme
    [CRTC_ADDR_MULTI.sch]
2025-03-29 Long overdue update...
    [Backplane-B_Cu.gbl, Backplane-B_Mask.gbs, Backplane-B_Paste.gbp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]

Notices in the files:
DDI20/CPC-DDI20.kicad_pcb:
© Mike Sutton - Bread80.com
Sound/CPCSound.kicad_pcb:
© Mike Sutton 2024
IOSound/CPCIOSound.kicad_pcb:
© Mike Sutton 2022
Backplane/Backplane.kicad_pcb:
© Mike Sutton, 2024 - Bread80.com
